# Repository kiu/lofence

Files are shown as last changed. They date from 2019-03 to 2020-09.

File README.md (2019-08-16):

# LoFence
LoFence is a [LoRaWAN](https://en.wikipedia.org/wiki/LoRa#LoRaWAN) capable IoT electric fence monitoring system running on the [The Things Network](https://www.thethingsnetwork.org/).

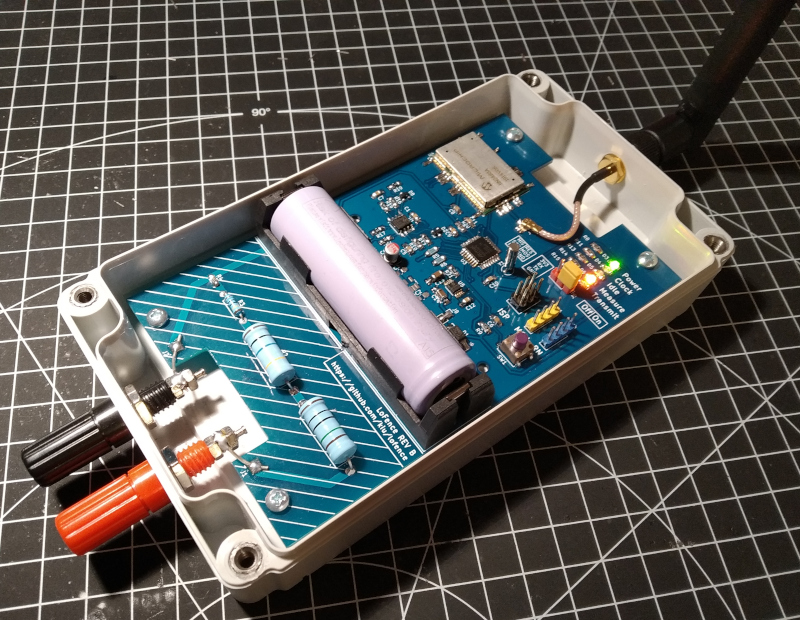
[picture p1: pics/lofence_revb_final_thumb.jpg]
lofence


# Backstory
A friend of mine is herding cattle and sheep on a small scale as a hobby. His setup is quite clever as his property has a creek running through, which enables him to let the animals live quite autonomously with minimal supervision. Unfortunately, he got called by the police a few times due to his sheep pulling a prison break. In theory a low maintenance system, but in reality things do happen. The car battery powering the electric fence energizer runs out of juice, a falling tree branch tears the fence down, or a tractor plows down a pole of the fence.

# Obvious solution
We need a monitoring system!

## Measuring
There are lots of ways to measure an electric fence. Try to hack the energizer’s built-in fault detection, measure current or do some fancy wave analysis of reflections on the line.

Too complicated for the initial build, let’s keep it simple by measuring voltage. Well, not a little voltage, but all the way up to 12 kV. Difficult, but a voltage divider with an op-amp will do fine. With this setup, we can measure any disconnects on the line between the energizer and the LoFence measuring point, even short circuits after the measuring point. Your mileage may vary though. This setup is heavily dependent on weather conditions, e.g. having dry soil will provide a different readout than after heavy rain.

## Connectivity
The more difficult challenge in a rural/agricultural area is connectivity. Cell coverage is quite spotty and of course it requires a monthly payment of some kind. Further, it’s such a 90’s solution to use a GSM module.

A few years ago LoRa appeared on the stage operating in the freely available [ISM bands](https://en.wikipedia.org/wiki/ISM_band) offering low speed, long range communication. Perfect for...sigh...IoT devices like the LoFence. While LoRa is great for point-to-point communication, LoRaWAN got established and offers a full suite of protocols enabling a standardized way to build communication networks based on LoRa. While there are commercial network operators like [Sigfox](https://www.sigfox.com) where you have to pay for their services, there is a global initiative called [The Things Network](https://www.thethingsnetwork.org/) to run an open LoRaWAN network that any device can join and use for free. Bingo.

Checking their [coverage map](https://www.thethingsnetwork.org/map) of course showed that the area of interest has no gateways in reach, but setting up a simple [gateway](https://raw.githubusercontent.com/kiu/lofence/master/pics/lofence_ttig.jpg) - in our case a [TTIG](https://www.thethingsnetwork.org/forum/t/ttig-the-things-indoor-gateway/22049) for ~80 Euro - easily solved the coverage problem. According to their [Fair Access Policy](https://www.thethingsnetwork.org/forum/t/limitations-data-rate-packet-size-30-seconds-uplink-and-10-messages-downlink-per-day-fair-access-policy/1300) our use-case of sending a few bytes of measurement data every few hours is perfectly fitted for their service. Let’s roll.

There are quite a few options to integrate LoRaWAN into your device. From the super cheap [RFM95W chipset](https://www.hoperf.com/modules/lora/RFM95.html) where your firmware has to do most of the action (e.g. used by the [Adafruit Feather](https://www.adafruit.com/product/3078)), up to the "expensive" turnkey solution like the [RN2483](https://www.microchip.com/wwwproducts/en/RN2483) which I chose. It does all the magic and will actively prevent you from breaking ISM band regulations regarding radio utilization. Nice.
 
## Build
The build is quite unspectacular. Spinning up a board with some AVR, put an antenna and the RN2483 on it, a big resistor divider with an op-amp and some resistors, debug LEDs and pin headers, an 18650 battery and a waterproof case. Et voila.

## Data Extraction
Having a node reporting its measurements to The Things Network is nice, but actually I want to do something with the data. Like sending an alert.

Extracting the data from TTN is easy, but I did it wrong anyways. First thing I stumbled upon was the [HTTP Integration](https://www.thethingsnetwork.org/docs/applications/http/). Everytime an uplink message is received from a node, the HTTP integration will trigger a POST message to a webserver of your choice. Great. So I wrote a Java service on my end to parse these messages and store them in a database for [grafana](https://grafana.com/) to [consume](https://raw.githubusercontent.com/kiu/lofence/master/pics/lofence_grafana_overview.png) later on. My implementation parses the uplink message, extracts the payload, stores the RSSI, SNR, number of gateways, etc. It can be found here: [ttn-http](https://github.com/kiu/ttn-http).

Later, I found out that there is a way nicer [MQTT Integration](https://www.thethingsnetwork.org/docs/applications/mqtt/), which also includes a ready to use Java implementation. A couple of hours could have been saved here.

The other thing I didn't figure out immediately is the [Payload Formats](https://raw.githubusercontent.com/kiu/lofence/master/pics/lofence_ttn_decoder.png) option in the TTN console. It lets you write simple javascript running inside The Things Network to decode your payload data and assign them to key-value pairs. When receiving a message through the HTTP Integration (or MQTT), that message will include the key-value pairs as json for easy consumption. Quite clever and easy to parse.

# Nitty-Gritty Details
Checkout the [pics](https://github.com/kiu/lofence/tree/master/pics) and [hardware](https://github.com/kiu/lofence/tree/master/rev_b) section including BOM, Schematic, PCB layout, firmware, etc.

# TTN
If you are inspired by this hack to build a LoRaWAN project on your own and join the The Things Network effort, register on their site and join their maker community on [slack](https://www.thethingsnetwork.org/community/toowoomba/post/join-us-on-slack).

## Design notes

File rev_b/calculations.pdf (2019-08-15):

Tabelle1

Seite 1

Ohm | 10000000 | 10000000 | 1000000 | 5800
Volt Drop | 5712,70791877 | 5712,707919 | 571,2707919 3,313370592884
Ohm Calc | 10050000 | 10070000 | 997000 | 5807,175
Ohm Real | 10050000 | 10070000 | 997000 | 5720
Volt Real | 5709,49195937 | 5720,854132 | 566,4043267 3,249581493293
| Standby | Measure | Transmit
mA | 0,012 | 20 | 50
Minutes | 59 | 0,5 | 0,5
mAh | 0,0118 | 0,166666667 | 0,416666667
Battery mAh | 3000
| Hours | Days | Weeks | Months | Years
Runtime | 5040,89 | 210,04 | 30,01 | 7,50 | 0,63

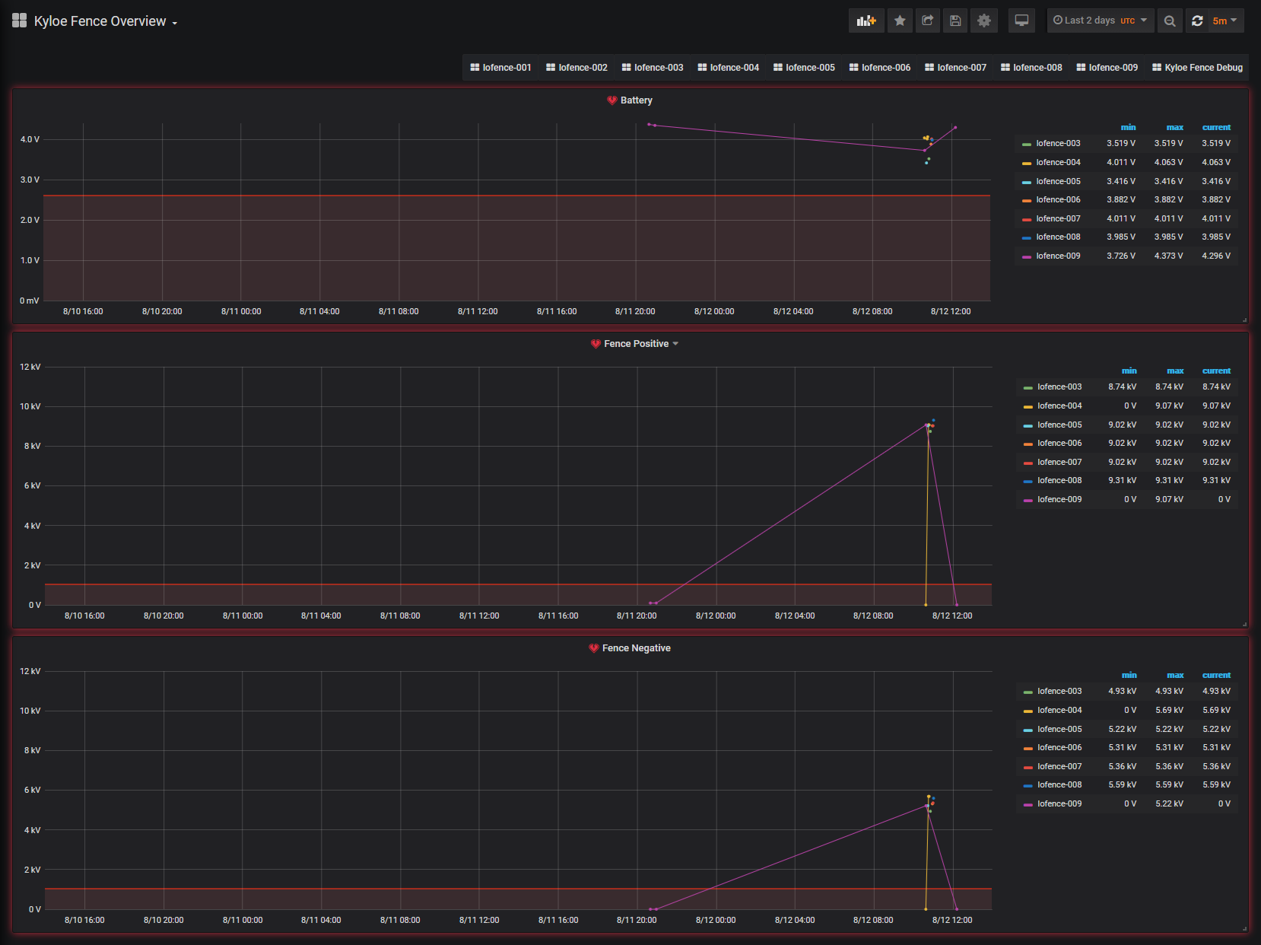
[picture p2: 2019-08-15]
pics/lofence_grafana_overview.png

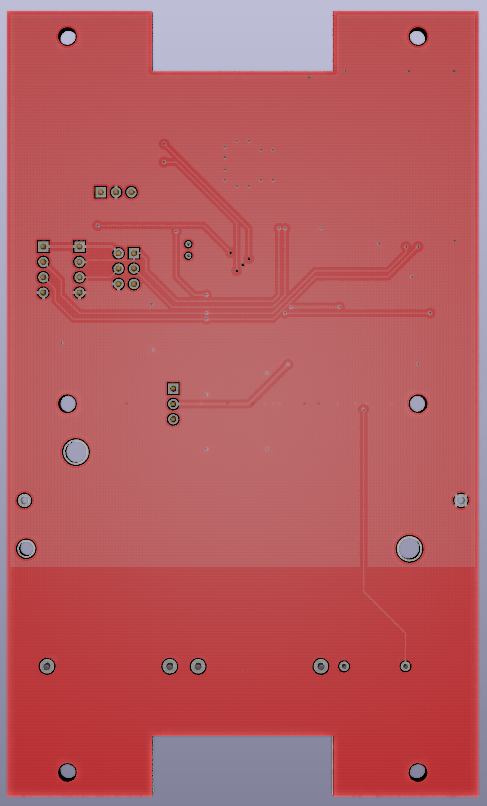
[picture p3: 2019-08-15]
rev_b/hardware/kicad_lofence_render_back.png

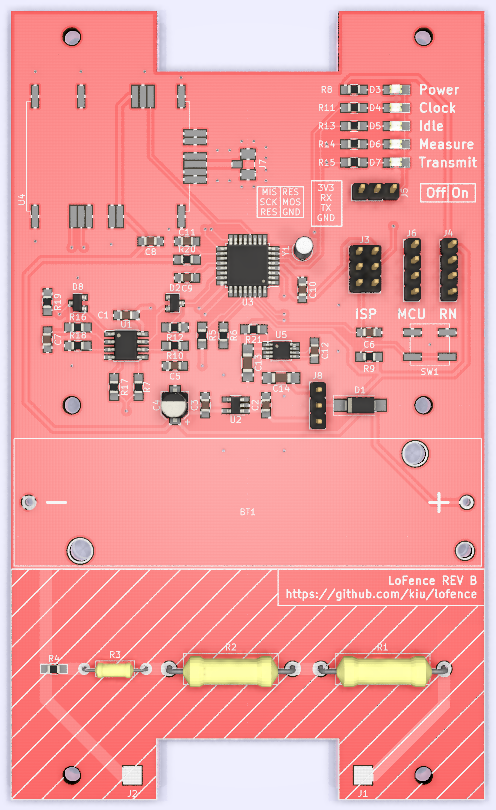
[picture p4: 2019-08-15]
rev_b/hardware/kicad_lofence_render_front.png

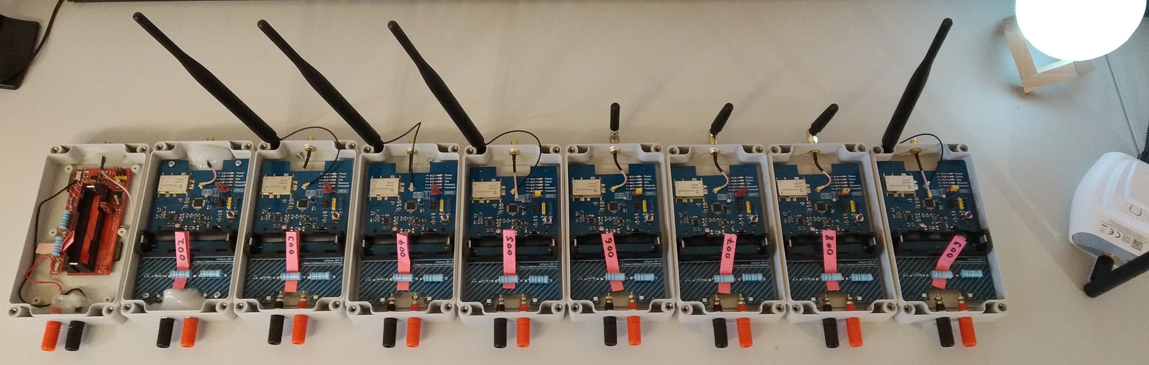
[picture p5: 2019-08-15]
pics/lofence_all_nine.jpg

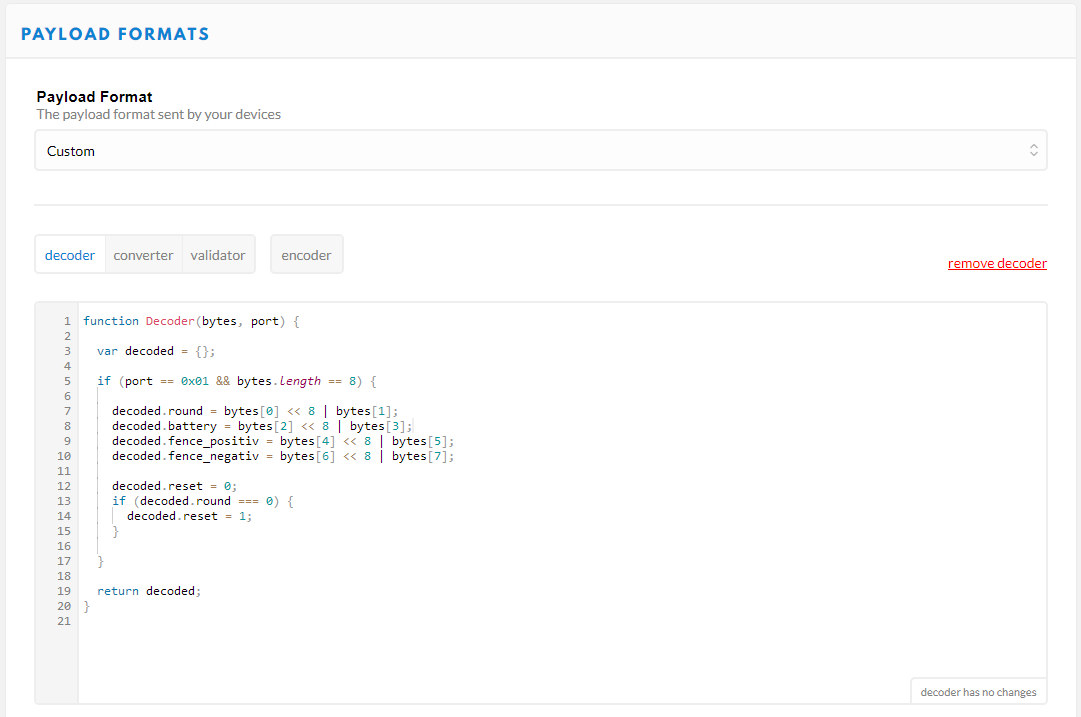
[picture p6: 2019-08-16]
pics/lofence_ttn_decoder.png

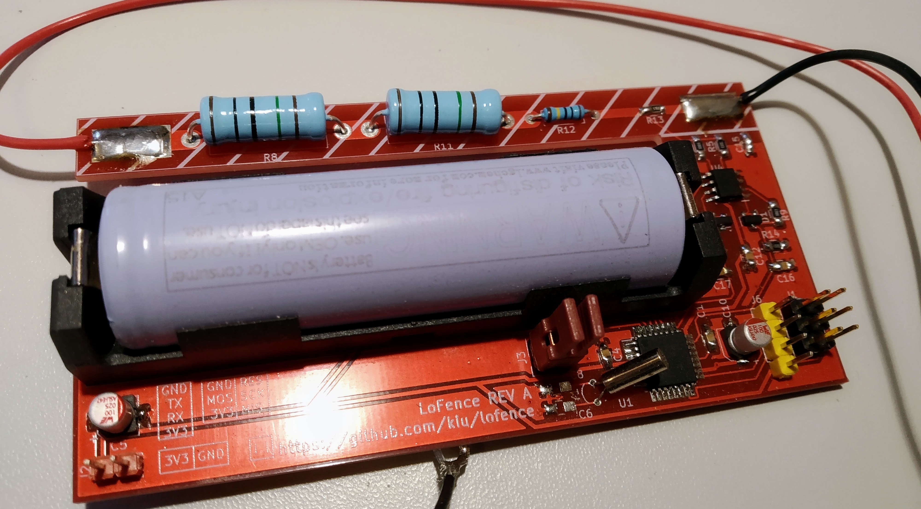
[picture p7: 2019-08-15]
pics/lofence_reva_proto.jpg

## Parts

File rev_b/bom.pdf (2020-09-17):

BOM
Symbol | Description | Req | +VAT | Price | Price (sum) | Provider | ID
| | | | MOQ 10
U1 | Opamp TLV9062 | 1 | 19 | 0,45 € | 0,54 € | http://www.mouser.de | 595-TLV9062IDR
(U2) | LDO MIC5504 | 0 | 19 | 0,10 € | 0,00 € | http://www.mouser.de | 998-MIC5504-3.3YM5TR
U3 | ATMega328PB-AU | 1 | 19 | 1,19 € | 1,42 € | http://www.mouser.de | 556-ATMEGA328PB-AU
U4 | RN2483 | 1 | 19 | 11,34 € | 13,49 € | http://www.mouser.de | 579-RN2483A-I/RM105
U5 | MCP1253-33X50 | 1 | 19 | 1,21 € | 1,44 € | http://www.mouser.de | 579-MCP1253T33X50IMS
J3 | 2x03 | 1 | 19 | 0,18 € | 0,21 € | http://www.mouser.de | 649-861400062YO2LF
J5 | 1x03 | 1 | 19 | 0,10 € | 0,11 € | http://www.mouser.de | 710-61300311121
J4, J6 | 1x04 | 2 | 19 | 0,14 € | 0,33 € | http://www.mouser.de | 710-61300411121
J7 | U.FL Straight Surface Mount Jack | 1 | 19 | 0,60 € | 0,72 € | http://www.mouser.de | 712-CONUFL001-SMD
C12, (C2, C3) | 1uF X7R 0805 | 1 | 19 | 0,04 € | 0,05 € | http://www.mouser.de | 963-EMK212B7105KG-T
C4 | 10uF 4x5.5 | 1 | 19 | 0,16 € | 0,19 € | http://www.mouser.de | 710-865080440002
C1, C5, C6, C7, C8, C9, C10, C11 | 100nF | 8 | 19 | 0,04 € | 0,37 € | http://www.mouser.de | 710-885012207098
C13, C14 | 10uF X7R 1206 | 2 | 19 | 0,12 € | 0,29 € | http://www.mouser.de | 963-LMK316B7106KL-T
R9 | 4k7 0805 | 1 | 19 | 0,04 € | 0,05 € | http://www.mouser.de | 667-ERJ-6ENF4701V
R5, R6 | 232R 0805 | 2 | 19 | 0,03 € | 0,08 € | http://www.mouser.de | 660-RK73H2ATTD2320F
R7, R10, R16, R17, R18, R21 | 100k 0805 | 6 | 19 | 0,03 € | 0,24 € | http://www.mouser.de | 71-RCG0805100KFKEA
R1, R2 | 10M 6kV 1W THT | 2 | 19 | 0,49 € | 1,16 € | http://www.mouser.de | 594-5073DM10M00J
R3 | 1M 700V | 1 | 19 | 0,28 € | 0,33 € | http://www.mouser.de | 594-5043DM1M000F
R4 | 5k76 0805 | 1 | 19 | 0,04 € | 0,04 € | http://www.mouser.de | 652-CR0805FX-5761ELF
R12, R19 | 1M 0805 | 2 | 19 | 0,07 € | 0,16 € | http://www.mouser.de | 71-RCA08051M00FKEA
R8, R11, R13, R14 | 60R 0805 | 4 | 19 | 0,04 € | 0,17 € | http://www.mouser.de | 652-CR0805FX-62R0ELF
R15 | 68R 0805 | 1 | 19 | 0,01 € | 0,02 € | http://www.mouser.de | 652-CR0805FX-68R0ELF
R20 | 47R 0805 | 1 | 19 | 0,01 € | 0,02 € | http://www.mouser.de | 652-CR0805FX-47R0ELF
D2, D8 | BAV70LT3G | 2 | 19 | 0,08 € | 0,19 € | http://www.mouser.de | 863-BAV70LT3G
D1 | Schottky Diode | 1 | 19 | 0,35 € | 0,42 € | http://www.mouser.de | 863-MBRA210LT3G
D3, D5 | LED Green 0805 2.10V | 2 | 19 | 0,15 € | 0,37 € | http://www.mouser.de | 604-APT2012CGCK
D4, D6 | LED Orange 0805 2.10V | 2 | 19 | 0,15 € | 0,35 € | http://www.mouser.de | 604-APT2012SECK
D7 | LED Red 0805 1.95V | 1 | 19 | 0,15 € | 0,18 € | http://www.mouser.de | 604-APHCM2012SURCK
Y1 | 32768hz | 1 | 19 | 0,18 € | 0,21 € | http://www.mouser.de | 449-LFXTAL002996BULK
BT1 | 18650 Battery Holder THT | 1 | 19 | 2,15 € | 2,56 € | http://www.mouser.de | 534-1043
SW1 | Pushbutton | 1 | 19 | 0,48 € | 0,57 € | http://www.mouser.de | 612-LL3301FF065QJ
- | Antenna 868Mhz | 1 | 19 | 2,56 € | 3,05 € | https://aliexpress.com | 32972870968
- | SMA/F.UL Pigtail | 1 | 0 | 1,29 € | 1,29 € | https://aliexpress.com | 32809523843
- | Binding Post Red | 1 | 19 | 0,31 € | 0,36 € | http://www.mouser.de | 474-PRT-09739
- | Binding Post Black | 1 | 19 | 0,31 € | 0,36 € | http://www.mouser.de | 474-PRT-09740
- | IP67 Enclosure 1555J2F17GY | 1 | 0 | 13,22 € | 13,22 € | http://www.conrad.de | 536525 – 62
- | Screw 2,9x6.5 | 6 | 0 | 0,07 € | 0,39 € | http://www.amazon.de | B01CLLUIJI
- | 18650 Battery 3350 mAh (Not recommended!) | 0 | 0 | 9,45 € | 0,00 € | B07NZVXJSP
- | PCB 130x78 | 1 | 0 | 1,60 € | 1,60 € | -

SUM
46,53 €
465,28 €

https://www.amazon.de

http://jlcpcb.com

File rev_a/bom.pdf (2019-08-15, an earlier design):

BOM

Page 1

Symbol | Description | Req | +VAT | Price | Price (sum) | Provider | ID
| | | | MOQ 10
U1 | ATMega328PB-AU | 1 | 19 | 1,19 € | 1,42 € | http://www.mouser.de | 556-ATMEGA328PB-AU
U2 | LDO MIC5504 | 1 | 19 | 0,10 € | 0,11 € | http://www.mouser.de | 998-MIC5504-3.3YM5TR
U3 | RN2483 | 1 | 19 | 11,34 € | 13,49 € | http://www.mouser.de | 579-RN2483A-I/RM104
U4 | Opamp TLV9062 | 1 | 19 | 0,45 € | 0,54 € | http://www.mouser.de | 595-TLV9062IDR
J1 | 2x03 | 1 | 19 | 0,18 € | 0,21 € | http://www.mouser.de | 649-861400062YO2LF
J2 | 1x02 | 1 | 19 | 0,07 € | 0,08 € | http://www.mouser.de | 649-861400021YO2LF
J3 | 2x02 | 1 | 19 | 0,12 € | 0,15 € | http://www.mouser.de | 649-86140042YO2319LF
J6 | 1x04 | 1 | 19 | 0,14 € | 0,16 € | http://www.mouser.de | 710-61300411121
C2, C3 | 1uF X7R 0805 | 2 | 19 | 0,11 € | 0,27 € | http://www.mouser.de | 81-GRM21BR71C105JA1K
C5, C10 | 10uF 4x5.5 | 2 | 19 | 0,16 € | 0,37 € | http://www.mouser.de | 710-865080440002
C1, C4, C9, C11, C12, C13, C16, C17 | 100nF | 8 | 19 | 0,04 € | 0,37 € | http://www.mouser.de | 710-885012207098
R2 | 4k7 0805 | 1 | 19 | 0,04 € | 0,05 € | http://www.mouser.de | 667-ERJ-6ENF4701V
R3, R4 | 232R 0805 | 2 | 19 | 0,03 € | 0,06 € | http://www.mouser.de | 660-RK73H2BTTD2320F
R5, R6, R7, R9, R10 | 100k 0805 | 5 | 19 | 0,03 € | 0,20 € | http://www.mouser.de | 71-RCG0805100KFKEA
R8, R11 | 10M 6kV 1W THT | 2 | 19 | 0,49 € | 1,16 € | http://www.mouser.de | 594-5073DM10M00J
R12 | 1M 700V | 1 | 19 | 0,28 € | 0,33 € | http://www.mouser.de | 594-5043DM1M000F
R13 | 5k76 0805 | 1 | 19 | 0,04 € | 0,04 € | http://www.mouser.de | 652-CR0805FX-5761ELF
R14, R15 | 1M 0805 | 2 | 19 | 0,07 € | 0,16 € | http://www.mouser.de | 71-RCA08051M00FKEA
D1, D2 | BAV70LT3G | 2 | 19 | 0,08 € | 0,19 € | 863-BAV70LT3G
L1 | 10uH 0805 | 1 | 19 | 0,06 € | 0,07 € | http://www.mouser.de | 963-LBR2012T100K
L2 | Ferrite 0805 220R 2A | 1 | 19 | 0,06 € | 0,07 € | http://www.mouser.de | 81-BLM21P221SG
Y1 | 32768hz | 1 | 19 | 0,18 € | 0,21 € | http://www.mouser.de | 449-LFXTAL002996BULK
BT1 | 18650 Battery Holder THT | 1 | 19 | 2,15 € | 2,56 € | http://www.mouser.de | 534-1043
- | Antenna 868Mhz | 1 | 19 | 6,03 € | 7,18 € | http://www.mouser.de | 815-CAQ190012-S868
- | Binding Post Red | 1 | 19 | 0,31 € | 0,36 € | http://www.mouser.de | 474-PRT-09739
- | Binding Post Black | 1 | 19 | 0,31 € | 0,36 € | http://www.mouser.de | 474-PRT-09740
- | IP67 Enclosure 1555J2F17GY | 1 | 0 | 13,22 € | 13,22 € | http://www.conrad.de | 536525 – 62
- | 18650 Battery 3350 mAh (No Protection Circuit, Amazon Link not recommended) | 1 | 0 | 9,45 € | 9,45 € | B07NZVXJSP
- | PCB 100x50 Red | 1 | 0 | 1,41 € | 1,41 € | -

SUM
54,26 €
542,64 €

http://www.mouser.de

https://www.amazon.de

http://www.seeedstudio.com

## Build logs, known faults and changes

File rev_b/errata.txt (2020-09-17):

1) Power supply
I never used a DC to DC converter before and wasn't sure if it could interfere with the RN2483 or ADC.
Therefore in addition I placed a LDO as a backup on the board as well.
The DC to DC converter works fine, so the LDO (U2, C2, C3) can be left unpopulated.

2) Resistor divider
Instead of
  [Fence+]--[10M]--[10M]--[1M]--[Measure]--[5k8]--[Fence-/GND]

I probably should have done
  [+12kV]--[10M]--[1M]--[Measure]--[5k8]--[GND]--[10M]--[Fence-]

3) The BOM of REV B was published with a wrong resistor value for R4. The correct value is 5k76.

4) Fixed silkscreen for ISP connector (3V3 in upper right corner instead of RES), but did not regenerate gerbers and other exports.

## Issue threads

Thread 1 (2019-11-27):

How to re-program RN2483 with your board layout?

kevinkngo, 2019-11-27:
Hi kiu,

I really appreciate you sharing this project. This is my first IoT project where I've started to enter the world of AVRs and PCBs (which is very exciting!).

I have actually gotten your PCB design fabricated, then I soldered on the components you listed in your BoM and loaded the firmware you provided onto the MCU... And it works great.
[Note: I actually have the RN2903 instead of the RN2483 - but they both work and are programmed very similarly].
I am currently trying to re-program the RN2903 soldered onto my PCB using the LoRaDevUtility ([Microchip documentation](http://ww1.microchip.com/downloads/en/devicedoc/40001847a.pdf)) and the RN UART pins you have provided.

However, I believe that due to the way you have set out your board, it is very difficult to do this. I could initially see the RN2903 in the LoRaDevUtility (see screenshot #1), but had to continuously hold down SW1 to keep the UART connection "alive".
I then tried to update the firmware on the RN2903 but I accidentaly "bricked" the chip currently on my board because the UART connection disconnected while the firmware was updating. Now whenever I try to upload firmware onto the RN2903 now, it keeps disconnecting and does not allow me to upload any firmware (see screenshot #2).

I am more than happy to grab another RN2903 and try again, but I'm hoping that you could provide some advice before I continue.

Do you have any recommendations about how I can re-program the RN2903/RN2483 using your board layout? Have you tried uploading different firmware onto the RN2483 yourself?
Since you manufactured so many boards, I am curious whether if you've thought about how you would update the firmware on the RN2483 on these boards (without taking it off?).

Thanks,
Kevin

Screenshot #1 - initially, can see RN2903 in LoRaDevUtility:
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

Screenshot #2 - cannot stay connected to RN2903 and upload firmware. Continuously disconnecting like below (I am using COM4 as my UART serial port):
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

kiu, 2019-11-27:
Hi Kevin,

I have to admit, I didn't think much about how to upgrade the firmware of the RN module. Or at least not in an user friendly way.
I would probably flash the AVR with a new config disabling the RX/TX pins, so they won't interfere with the RN module. Then upload the the RN firmware as you did.

If the RN module leaves bootloader mode, you could try to send the "eraseFW" command.

Hit me up on https://www.thethingsnetwork.org/community/toowoomba/post/join-us-on-slack (user: kiu).

kiu, 2019-11-29:
For the record.

Flashing a NOP version of lofence with RX/TX pins disabled (Atmel Start Config) and issuing a single RESET does the trick.

`int main(void) {
	atmel_start_init();
	_delay_ms(100);
	RN_RESET_set_level(false);
	_delay_ms(100);
	RN_RESET_set_level(true);
	_delay_ms(100);
	while (1) {
	}
}
`

jpmeijers, 2021-11-03:
I was struggling a little to do the firmware upgrade. Mostly because I am not familiar with Atmel Start. So let me document what I did in case someone else stumbles upon this thread.

1. Comment out the content of the `int main(void)` function and replace it with the contents of the main function as posted above.
2. Open src/driver_init.c and comment out the lines `USART_0_initialization();` and `USART_1_initialization();`.
3. Upload to LoFence board.

Because I could not find the Microchip firmware upgrade tool from an official source, and the one I did find didn't want to work, I looked for a different way to flash the firmware. I ended up using https://github.com/SodaqMoja/RN2483FirmwareUpdater

Luckily I had a Sodaq Explorer at hand to do the update, but I had to change the firmware to program the external RN2483 and not the onboard one on the Explorer. In RN2483FirmwareUpdater.ino on line 17 I replaced `Serial2` with `Serial`. `Serial` is the UART on pin 0 and pin 1.

Connection between the Explorer and LoFence is as follows:

| Explorer | LoFence J4 |
| -- | -- |
| 3.3V | pin 1 (3.3v) |
| D1 (TX) | pin 2 (RX) |
| D0 (RX) | pin 3 (TX) |
| GND | pin 4 (GND) |

Closed 2019-11-29.

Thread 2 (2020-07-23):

missing symbols

toozie21, 2020-07-23:
Nice design!

I am new to KiCad and when I opened your project there were missing symbols for the schematic (like for the RN2483).  Are those symbols something that you drew by hand? I haven't looked at the PCB yet, but I will let you know if I see similar issues there.

kiu, 2020-07-23:
Uh, thanks for pointing that out. I accidentally gitignored the cache.lib file.
Please update and check again.

toozie21, 2020-07-23:
> Uh, thanks for pointing that out. I accidentally gitignored the cache.lib file.
> Please update and check again.

Thank you, that did solve that issue.  Though it seemed to cause a different one after I updated...
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

kiu, 2020-07-23:
Odd. I did a clean install of kicad on a machine where I never used kicad on before. Did a git clone and get no errors. I do get a wizard though, but that works fine.

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

toozie21, 2020-07-23:
Weird. What version of KiCad?

kiu, 2020-07-24:
I installed latest stable 64bit Windows Version, that is 5.1.6
https://kicad-pcb.org/download/windows/

toozie21, 2020-07-24:
> I installed latest stable 64bit Windows Version, that is 5.1.6
> https://kicad-pcb.org/download/windows/

I was using Ubuntu and it was one minor version behind.  I installed it on my Windows laptop to make it easier and it seemed to load up fine, so I think you solved the problem, thanks!!

Closed 2020-07-24.

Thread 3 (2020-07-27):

Question on battery

toozie21, 2020-07-27:
Not an issue, just a question.

In the BOM you say this for the battery
`18650 Battery 3350 mAh (Not recommended!)`
But I don't see any explanation anywhere for why you don't recommend it. Did you have issues? TIA

Alex9779, 2020-08-20:
Yeah I am interested in an answer on this too...

kiu, 2020-08-20:
If I remember correctly, the battery doesn't have a security circuit. Therefore I wouldn't want to recommend it. Otherwise nothing wrong with it. Works fine for me.

toozie21, 2020-08-20:
> If I remember correctly, the battery doesn't have a security circuit. Therefore I wouldn't want to recommend it. Otherwise nothing wrong with it. Works fine for me.

That is correct. I thought that if you take an additional step, it would need the protection and probably charging circuitry. I think it is perfect as is though.

I just wanted to make sure that you didn't have one blow up on you, and we're suggesting a different brand 😁.
 Thanks again for the awesome design.

Closed 2020-08-20.

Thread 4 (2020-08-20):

Question on voltage divider errata

Alex9779, 2020-08-20:
Just another question on the errate you did on the voltage divider.
Could you just explain what you meant with that?
I am thinking of rebuilding your design but also I am puzzled what the difference is as I am not really sure what you mean with "Fence+", "Fence-" and "12kV".
My fences have just one pole, when I measure them using a normal tester the tester is connected to the ground by a nail and one end goes to the fence. There is no + and - but just a +, - is ground...
What am I missing?
Thanks for your efforts in advance...

kiu, 2020-08-20:
The left side is REV B and right side is the potential improvement. The hot wire of your fence is connected at the top, bottom has the earth connection (rod/spike in the ground)

I am wondering in the errata, if its clever to switch to the design on the right, where the pcb ground and earth of the fence are decoupled by 10M.

Does that help?

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

Alex9779, 2020-08-21:
Yeah cool thanks, I think I will calculate that for me to see the numbers too but the changed labels helped a lot...

frederickjh, 2023-04-10:
> Yeah cool thanks, I think I will calculate that for me to see the numbers too but the changed labels helped a lot...

@Alex9779 Thanks for posting this issue. I was wondering the same thing. Thanks to @kiu for the diagram explaining it.

Did either of you ever build and test this improved voltage divider?

Just wondering and trying to not reinvent the wheel.

I see one commercial product (Fence Hawk) on the market that builds the voltage divider in a piece of PVC pipe with PVC caps on the ends and stainless steel bolts in the caps to connect to the fence and ground. They then run a low voltage wire run to the detector circuit. This seems like an interesting design.

Alex9779, 2023-04-10:
I built them according to the errata and they have been working fine since then, that is the changed voltage divider and also removing the obsolete LDO circuit.

Closed 2020-08-21.

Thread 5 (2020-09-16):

R5, R6 BOM order number wrong

Alex9779, 2020-09-16:
R5 and R6 in the BOM have a 0805 footprint but the Mouser part number resolves to resistors with a 1206 case.
Think it is just a typo because there exists pretty much the same resistors in 0805 with order number 660-RK73H2**A**TTD2320F instead of 660-RK73H2**B**TTD2320F.

kiu, 2020-09-17:
Good catch!
https://github.com/kiu/lofence/commit/79e2fb9587586af6832cf9452c6af343f834de3f

Closed 2020-09-17.

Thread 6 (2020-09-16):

Silk screen of ISP has 'RES' twice

Alex9779, 2020-09-16:
No idea if this is intended but doesn't have to be 'RES' in the upper right corner '3V3' of the silk screen for the ISP connector?

kiu, 2020-09-17:
Uh, yes.
https://github.com/kiu/lofence/commit/0af46fa1ba887103b02b0fecc750f6ab15897427

Closed 2020-09-17.

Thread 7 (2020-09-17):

Issues regarding the RN2483 LoRa module and LoRa logic

Alex9779, 2020-09-17:
Taking the next step to get the project to use I had to set up a LoRa gateway (did this already earlier and played with some other modules), learned about TTN and ChirpStack.
And I stumbled over a few things I would like to mention, no idea if you are aware of them or not.

The overall usage of LoRa does not seem to fit any guidelines, at first you use ABP for joing, that's ok but not recommended so I changed the firmware to use OTAA which then has some other things to follow like saving the join information accross power cycles. I am still working on that, I think of totally rewriting the firmware, if ready I will put it up in my fork.

Another thing is that the module uses not the EU868 specs if you do a "sys factoryRESET", you have to do a "mac reset 868" also to load the EU868 channel defaults deactivating the use of channel 3-15 (actually 7, because 8-15 are disabled by default). This has no effect if using TTN because a TTN gateway listens on all 8 channels but recommended is to use only the first 3 (0-2). I had that problem when using a gateway created with ChirpStack which just listens on channel 0-2 by default.

Last the data rate. It is left at default DR0 which is SF12BW125 it seems with no ADR while ADR is mandatory for SF11 and SF12 and based on https://avbentem.github.io/airtime-calculator/ttn/eu868/8 at DR0 only 20 messages per day are allowed and accepted by TTN but the firmware does a measurement once every hour. So if your devices use that firmware in public I would at least recommend to change it to use DR2.

Just a side note: thanks for the great project, I don't think I would have been able to get a working PCB without many prototypes and in a short time as I have, saved my a lot of trouble, time and money...

kiu, 2020-09-17:
Thanks for sharing your insights!

> The overall usage of LoRa does not seem to fit any guidelines, at first you use ABP for joing, that's ok but not recommended so I changed the firmware to use OTAA which then has some other things to follow like saving the join information accross power cycles.

As the area I am trying to cover has really low coverage, I chose to use ABP to increase the chance of packets reaching the gateway. Didn't want to rely on additional OTAA traffic. But you are right, it is recommended and way more convenient.

> I am still working on that, I think of totally rewriting the firmware, if ready I will put it up in my fork.

Sweet.

> Another thing is that the module uses not the EU868 specs if you do a "sys factoryRESET", you have to do a "mac reset 868" also to load the EU868 channel defaults deactivating the use of channel 3-15 (actually 7, because 8-15 are disabled by default).

Hmmm, odd. I checked the Command Reference and everything points me towards that the 868 parameters are the defaults of the module. It explicitly says "The default settings consider only the three default channels (0-2), and their default duty cycle is 0.33%.", but I never verified it. Do you have more information on this?

> Last the data rate. It is left at default DR0 which is SF12BW125 it seems with no ADR while ADR is mandatory for SF11 and SF12

True, I didn't know that. https://github.com/kiu/lofence/commit/61f52703dbc37d511e447d4d42a77dffc8d7a1df

> and based on https://avbentem.github.io/airtime-calculator/ttn/eu868/8 at DR0 only 20 messages per day are allowed and accepted by TTN but the firmware does a measurement once every hour. So if your devices use that firmware in public I would at least recommend to change it to use DR2.

Also true, changed it as well.

Alex9779, 2020-09-17:
Yeah well, the module surprised me also.
The overall appearence made me also think this is plug and play but there are some drawbacks.
Trying to get OTAA working the way its meant to be, that is just one join when the device is provisioned and hopefully never again, which is considered best practice, lead into other issues.
I found an Arduino lib for the module, but this is not doing this also very well, I think of taking that and rewriting and using it for this project, most of the code should be copy paste but class init and comm must be changed for the Atmel.

Alex9779, 2020-09-17:
This is the lib I want to adapt: https://github.com/jpmeijers/RN2483-Arduino-Library

Alex9779, 2020-09-17:
BTW I checked all I wrote by directly commanding the module with a terminal app running firmware 1.0.5, that version you get if you order using the number in your BOM, no idea if the other available version does the same, reflashing seems not so easy, I found a script on Github too but I don't want to try just to prove something...

Alex9779, 2020-10-08:
Well it seems I didn't have the time (yet) to do what I wanted, I just modified the firmware to use OTA and reorganized a little.
I wrote a simple python script for initializing a fresh RN2483 module for OTA.
My 6 devices are up and running, 2 in the wild, 4 on my desk waiting for cables to connect them to the fence.
Monitoring works just fine.
Unfortunately I modified the PCBs with a KiCAD nightly build and I am not sure if I should publish that yet. I will when v6 is released and then also along with my changed firmware, so maybe January...

Closed 2020-10-08.

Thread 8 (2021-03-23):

op-amp power supply

4Inno, 2021-03-23:
Hey there,
great project! Isn't the op-amp missing the supply power? ADC_POWER is only conntected to the uC. Or am I missing something?
Best regards

kiu, 2021-03-23:
The ADC_POWER is directly powering the opamp from the uC everytime a measuring cycle is run. That way the op-amp does not consume any power when its not needed as the uC can turn it off.

4Inno, 2021-03-24:
Thank you! I will close the issue.

Closed 2021-03-24.

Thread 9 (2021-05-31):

RN2483 send timeout?

thomasdupas, 2021-05-31:
What firmware of the RN2483 are you running, 1.0.5 or an earlier version? And what settings did you use on TTN side for the device?

I'm having some issues where the RN2483 sometimes doesn't give a response anymore to a TX command.
It would do multiple rounds OK, and then suddenly it acknowledges the command to send an unconfirmed message, but after ~1 hour it still sits there with no response on the UART from the RN seemingly (I didn't tap the UART yet directly from the RN in parallel, will try that). In the docs of the RN2483 there is a possible timeout response mentioned, so should it need to be set explicitly perhaps?

example:
```
Sleeping for 4320 seconds

Round: 3
Measuring
Measuring battery: 4684 mV
Measuring fence positive: 0 V
Measuring fence negative: 0 V

Transmitting
RN2483 wakeup and baud change
RN2483 RX clearing
RN2483 TX: mac join abp
RN2483 RX: ok
RN2483 RX: accepted
RN2483 TX: mac get upctr
RN2483 RX: 25
RN2483 TX: mac set pwridx 1
RN2483 RX: ok
RN2483 TX: mac tx uncnf 1 0003124C00000000
RN2483 RX: ok
RN2483 RX: mac_tx_ok
RN2483 TX: mac save
RN2483 RX: ok
RN2483 TX: sys sleep 86400000

Sleeping for 4320 seconds

Round: 4
Measuring
Measuring battery: 4658 mV
Measuring fence positive: 0 V
Measuring fence negative: 0 V

Transmitting
RN2483 wakeup and baud change
RN2483 RX clearing
RN2483 TX: mac join abp
RN2483 RX: ok
RN2483 RX: accepted
RN2483 TX: mac get upctr
RN2483 RX: 26
RN2483 TX: mac set pwridx 1
RN2483 RX: ok
RN2483 TX: mac tx uncnf 1 0004123200000000
RN2483 RX: ok
```

/edit: found some other references to this
https://www.thethingsnetwork.org/forum/t/rn2483-timing/36278
https://www.microchip.com/forums/m1101599.aspx

So for now I've put a (naive) 5 second timeout in the rn2483_rx() function to cope with this. Will let it run again overnight and see how it behaves

kiu, 2021-05-31:
Hmmm. Unfortunately I haven't seen this problem before. I have 10 devices running and I didn't observe a device being stuck. Or - to be more precise - I didn't see it while testing. The devices are in the field and maintained by friend. I wouldn't notice if he reboots devices sometimes.

I am pretty sure that all my devices run RN2483 firmware 1.0.5.

Adding the timeout is a good idea anyways. Please provide feedback on your experience.

kiu, 2021-05-31:
Actually I can see resets as I am monitoring them. But I don't know if they were intended (device was moved / battery changed) or because of a lock up.

Each spike is reset on a device.

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

thomasdupas, 2021-06-01:
For now it's going steady again, perhaps too soon to tell. But I guess the timeout doesn't hurt anyhow.

I saw a prior ticket with some potential changes ( https://github.com/kiu/lofence/issues/7 ) which didn't go through yet since kicad 6 isn't released yet. I'll probably hop on that wagon as well, since updating the keys and creating a custom hex file gets error-prone very quickly.

I'll probably create some pyserial wrapper around a json/config file which has the hweui's and TTN keys. Then it can do the RN<->TTN config mapping by itself and every AVR can have the same firmware (PS, why the EEPROM save every time, it's only altering those settings once, not concerned about EEPROM wear?).

Didn't use lorawan before, so have to read up on OTAA vs ABP and see what that entails possibly

kiu, 2021-06-01:
> (PS, why the EEPROM save every time, it's only altering those settings once, not concerned about EEPROM wear?).

I believe - its been a while - that the frame counter is only persisted on a "mac save". As I have enabled that for the devices in the TTN console, I need to ensure that the value is not lost. Otherwise the RN2483 on a reboot will start with frame counter 0 and the messages are discarded. There is probably no need to enable frame counters (replay attacks aren't a strong vector in my scenario).

> Didn't use lorawan before, so have to read up on OTAA vs ABP and see what that entails possibly

I didn't use OTAA for my devices, as there is really bad coverage in the area I am setting them up. OTAA - not on every message though - requires additional packets being transmitted to join the network and there would be a higher chance of packet loss.

Alex9779, 2021-06-01:
I followed this issue and because you mentioned #6 here my comment.
I wanted to change and use a ready to go lib for the RN module, but as it goes it didn't have the time and just changed the code to do what I need and thought was right.
That is burning the keys to the RN module using an extra script before programming the ATmega and then using soft ABP joining.
I recently switched to an OTAA rejoin when the device gets reset/restarted because of some issues witch my LoRa gateway sometimes having troubles with fCnt of packets and re-joining resets that counter and starts over... This is how my other LoRa sensors are doing it and as the devices have a very long uptime I don't see an issue there anymore. Initially I thought re-joining should not occur on every restart but what I really meant was not too often and if a device is up for a year and then the battery has to be changed this is not too often for a re-join...
One or two times since I use the devices I had a hanging RN module, the device didn't post updates, I opened it and the transmit LED lit continually but I wasn't able to debug and get the cause if it. A restart solved it...
I thought of implementing a watch dog but I have no idea if that is even possible with the ATmega chip...

thomasdupas, 2021-06-01:
@Alex9779 "One or two times since I use the devices I had a hanging RN module, the device didn't post updates, I opened it and the transmit LED lit continually but I wasn't able to debug and get the cause if it. A restart solved it..."
That's exactly what I had yesterday / see start of issue ticket.

What I changed (apologies for the ugly code, this is outside my comfort zone ;-)) to have a ~5 second timeout
```
void rn2483_rx() {
	char nc = 0x00;
	uint8_t len = 0;

    // erase buffer_rn to make sure it doesn't contain data from prior read
    memset(buffer_rn, 0, 255);

    // do 5000 loops, bit naive way to yield a 5 second timeout
    for(int i = 0; i < 5000; i++){
        if (USART_0_is_rx_ready()) {
            nc = USART_0_read();
            buffer_rn[len] = nc;
            len++;
            if (nc == '\n') {
                break;
            }
        } else {
            _delay_ms(1);
        }
	}
	buffer_rn[len+1] = '\0';

	#ifdef DEBUG
	debug("RN2483 RX: ");
	debug(buffer_rn);
	#endif
}
```

Alex9779, 2021-06-01:
Well it is hard to test, maybe have a look in that lib and see if they have implemented some kind of watch dog:
https://github.com/jpmeijers/RN2483-Arduino-Library

thomasdupas, 2021-06-01:
no watchdog at first glance, but timeouts on the serial reads on many places
like
```
        _serial.setTimeout(30000);
        receivedData = _serial.readStringUntil('\n');
        _serial.setTimeout(2000);
```

Alex9779, 2021-06-01:
Yeah well, as already said I have it running in a way it suits me...
If I wanted to sell those devices then yes, the firmware would need a rework, but for now I don't need it.
A hang rarely happens, most devices didn't have a single hang until the battery ran out so...

kiu, 2021-06-01:
It is my understanding that once the module hangs, it won't recover later on. Can you confirm that? If that is the case, you would need to reset the module in case your timeout is triggered: rn2483_init();

It is also possible to integrate the hardware watchdog into the system, but be aware that the current code immediately starts to send a packet through TTN. A device with problems restarting through the watchdog all the time, could violate the fair use policy of TTN. The RN2483 itself covers any regulatory violations, but who knows what the module actually will do, if it hangs/crashes. Probably best solution for a watchdog solution would be to go to sleep after startup to insure proper delays in case the device goes roque.

Alex9779, 2021-06-01:
As far as I can tell from other LoRa devices TTN fair use is one thing, local regulations something other and what a device does also.
I don't use TTN because for my fence monitoring the fair use is not enough for me to get alerts in time. I have my own gateway on Chirpstack.
TTN just ignores packets above the fait use, you won't get them in your app.
What happens if your device constantly breaks local restrictions I can't tell... I think it depends if you really interfere with something important then they come and analyse.
My approved devices for example try to join every 30 seconds after a reboot I think but I have no idea for how long if they don't get an answer.
That is much above what TTN allows.
I agree if the module hangs and you have to reset you also reset the regulation restrictions and that way you can break them, send more packets than allowed.
And as far as I know the approved devices have some kind of timeout, they try but stop after some time and require a manual reset to try again to not overwhelm the band...

thomasdupas, 2021-06-01:
Just documenting it here, for future reference.
I tried the absence of the eeprom save command, but that's indeed needed to keep track of the frame counter. It confused me that the docs said it was needed after `mac set <xyz>` commands (and there exists an explicit downlink/uplink frame counter set command), but implicitly the module is bumping that every transmission I guess, hence the need for the save.
Tested here below, The last 2 cycles was with firmware without the mac save command (and a reset in-between)

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

As for the RN reset / hang, very possible indeed, but hard to provoke to be certain. For testing purposes I'll leave it out for now and see what happens.

Alex9779, 2021-06-01:
I used that mac save in my firmware but only every 100 uplinks to save the eeprom from wearing out, on a new start I increased the counter by 100 to be after any count between where the gateway might be...
But I changed to a rejoin on a reset so no need to save for now...

Alex9779, 2021-08-25:
I want to share some recent impressions on this topic.
I do not use TTN but have an own gateway running ChirpstackOS. I stumbled over some special handling in the Chirpstack code regarding the RN2483 and the LoRa power index sent to the device if in ADR mode.
The issue seems to be that the RN2483 does not handle a power index of 0 properly.
Though this seems to be taken care of in the base code of Chirpstack I created an own ADR algorithm plugin and changed it so power index 0 is never used despite some other changes I want to have for my installation.
Since I use (about 1 month at the time of writing) this ADR algorithm for my LoFence devices I never had a hanging device again.

Alex9779, 2021-08-25:
here is the code in Chirpstack I referred: https://github.com/brocaar/chirpstack-network-server/blob/3971570b77c79c1cfd184b6f06a4f1770b5a0db0/internal/maccommand/link_adr.go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

Alex9779, 2021-08-25:
Oh and yes I know there is firmware 1.0.3 mentioned, i checked one device and I have 1.0.5 on it.
But since there was a problem in 1.0.3 no idea if the fix works properly.
I will monitor and see how long the system is stable with the new ADR for the RN2483 and report if I see a hanging device again...

Alex9779, 2021-09-20:
About a month passed and system still stable, no hanging devices after changing to my ADR algorithm.
I had one device having an issue but it turned out the crystal had a connection issue and the clock didn't get a signal so the device didn't wake up after initial join and first measurement.
I changed batteries of all six devices yesterday, all joined without issues and sent ~200 updates...

Closed 2023-04-12.

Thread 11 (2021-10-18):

"round" counter really necessary

jpmeijers, 2021-10-18:
LoRaWAN has a frame counter that also increments every transmission. Does the "round" counter really add any extra usefulinformation?

Currently this project uses ABP and the frame counter will not reset during a power cycle. One will therefore not see a restart in the frame counter, and this "round" counter might be useful.

I'm however of the opinion one should switch to OTAA. I'll file a PR for OTAA in the coming days.

Closed 2023-04-12.

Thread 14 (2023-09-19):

Impulse measurement

Inrebusillis, 2023-09-19:
I have built the divider and the amp circuit and send the signal to a Dragino LSN50 V2 and V3 to make easy the LoRa part for me as I have this module from othes project,
everything working excellent BUT:
- the fence ( big bully up to 12kV is powered by voltage impulse ( about 30 ms)  every 0.8 seconds so Is not constantly all the time powered ( my unsterstand)
- the LNS50 wake up take a measurement from the circuit and go sleep for the next 20 minutes

obviusly the probability that the impulse is done just when the module is awake is really low.

How can measure the voltage and "hold the value" ( measure the impulse) till the sending module is awake again?
Or I missing something ?
thanks

jpmeijers, 2023-09-19:
Your understanding is correct.

Each time the Atmega 328p wakes up (every hour), the firmware samples the ADC for 15 seconds, at a rate of 250kHz, storing the max and min values it encounters. It will therefore measure more than 15 pulses in a row, storing the maximum sample, of the maximum pulse, and report that as the voltage.

You can have a look at how the ADC is set up here:
https://github.com/kiu/lofence/blob/9a1d09bd57b84be4a4ec193df7fd8c69c1f981a8/rev_b/firmware/LoFence/main.c#L52

Inrebusillis, 2023-09-19:
so to built it I have to use the full project.
let me ask you: I have a friends/farmer that need to 7 of these,
I am already running a TTI network.
Can I use your project? which conditions?
I would like to have a short chat with you, could you send me your tel via PN?
Thanks

Alex9779, 2023-09-19:
I tried the same about a year ago, I developed several iterations of a "sensor module" using just the divider and the opamp, one verison also used a smaller AVR MCU but I wasn't able to work reliable.
One problem is the spefic characteristics of the ADC of the ATmega 328PB of the original design.
The other is the firmware of the LSN50 which is not capapable of "waiting" a defined time frame for a function running in the background to get the max value of several impulses.
I tried to program a new firmware using the ADC of the LSN50 itself but didn't succeed.

ATM I am finalizing a V2 version with a smaller case, a different LoRa module and two 18650 or 18500 batteries, that is not fixed yet...

Alex9779, 2023-09-19:
This is how one version looked like:
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

And this how my current design looks like:
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

Alex9779, 2023-09-19:
One thing to consider is that the circuit with the OpAmp to "store" the peak and let the LSN ADC measure that is that it also uses current and from what I calculated the LSN battery would last about 2 years when measuring every 5 minutes like I do now.
And that battery is not chargeable.
This was something I wanted to accept and which also would lead to some money each year or two to keep it running...
In the end I chose to redesign the original device to have more lifetime, not to deep discharge the batteries when they run low and I dont change then right away and a different case which can be opened without dismounting it every time...

Alex9779, 2023-09-19:
@Inrebusillis Tried to send you a mail on your homepage, no idea if that worked, contact me by mail if you want to talk, think you are in  Germany too...

Inrebusillis, 2023-09-19:
thx,
sent you a mail

Inrebusillis, 2023-09-25:
thanks,[jpmeijers](https://github.com/jpmeijers) you nailed it.
Each time the Atmega 328p wakes up (every hour), the firmware samples the ADC for 15 seconds, at a rate of 250kHz, storing the max and min values it encounters. It will therefore measure more than 15 pulses in a row, storing the maximum sample, of the maximum pulse, and report that as the voltage.

Closed 2023-09-25.

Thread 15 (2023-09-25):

DualOp Amp Use

ADebla, 2023-09-25:
Hello everyone,

I don't really think we could qualify this post as an issue but I need some more understanding about the hardware.

I have tried to simulate the circuit with the dual OP Amp as in the schematic.

I am actually wondering why it is the use of these twos ? I mean, as long the voltage divider gives the peak of the pulser trough the ADC (ofc, we need to hold the peak value to sample it).

So could maybe someone explain me a bit the use of the dual op amp please ? Because I have the impression that only the voltage divider with a cirucit that hold the value feeding the adc with his negative potential to ground will be enough.

Please do not hesitate to correct me if I am misunderstanding the concept.

Kind regards,
Antoine

jpmeijers, 2023-09-26:
"Ground" in this circuit is just some arbitrary reference that remains relatively stable over the time it takes for a single pulse to pass. Because the sensor is physically connected to the fence wires, this ground value is roughly the same as the fence idle voltage, which may or may not be the same as the actual earth voltage - due to static buildup this could be different.

If you would look at the fence pulse on an oscilloscope, you will see the pulse do not only go high above the idle voltage, but also low below the idle voltage. When I compared the readings of this sensor with another fence tester, it looks like other testers report the voltage difference between the pulse peak and trough. So in other words Vmax-Vmin.

This tester measures both the positive peak voltage as well as the negative minimum voltage. This negative voltage measurement requires the second inverting opamp cirtcuit, while the maximum voltage is measured using the normal non-inverting opamp. That's why we need both opamps.

I hope this makes sense, and I hope I did not make any mistake in my description.

ADebla, 2023-09-28:
Thank a lot for the explanation ! Indeed, it does make sense now, I did work with some fence energizer but I have to say that I did not look at the negative part after the pulse.

In addition to your explanations, I understand now with the simulation does not work. In fact, I have simulated not with a pulse but with a 3.3V DC continous voltage which refer to the 12kV maximum before the voltage divider.

As it is continous, it can output and so simulate the positive side but not the negative one. I will try to simulate again and give some results here.

As a last question and for the needs of the simulation, do you have any example of the idle voltage of the fence you worked with and where did the negative part of the pulse have been gone so far ?

Kind regards,
Antoine

ADebla, 2023-09-28:
It is indeed really relevant, thanks a lot for the help and the informations.

I think we can close the "issue" !

Closed 2023-09-28.

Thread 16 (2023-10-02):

New resistor configuration in errata.txt

djorr5, 2023-10-02:
Hi, I saw this had activity starting up not that long ago and thought I might join the party ;).

In the errata.txt. OP makes mention of changing the resistor configuration from:
 [Fence+]--[10M]--[10M]--[1M]--[Measure]--[5k8]--[Fence-/GND]

to:
 [+12kV]--[10M]--[1M]--[Measure]--[5k8]--[GND]--[10M]--[Fence-]

Assuming so that the Fence- is possible earth (as in poke in an earth spike) and GND is ground referance on the PCB. However when I put the updated resistor values into falstad.com and with a 12kV input I was reading 6.28V at the opamp input. Isn't this too high for the opamp?

Or am I completely missing something?

Sorry for making it an issue but I saw some other do it and thought this would be the best way.

Great project by the way!!

jpmeijers, 2023-10-02:
Did you remember to move the curcuit's GND connection to between the 5k8 and 10M resistor?

"GND" is just some arbitrary chosen reference. The errata changes this reference to be isolated from the fence's negative line (for two line systems). This is good, because both the "positive" and "negative" lines will shock you if you touch them, and connecting one of these lines to GND will put the circuit and antenna at that same level - ie. the antenna will shock you just like the fence.

Maybe share a screenshot of your two simulations so we can see if there isn't a mistake in there. Circuit theory says the two voltage divider circuits should result in the same voltage between GND and Measure.

djorr5, 2023-10-03:
I did move the GND connection. But what I may not have done correctly is earthed the return wire of the fence. Here (australia) majority of fences have an earth spike and run just the one hot wire. So I was just wondering if that would affect the new layout of your voltage divider. Please see screenshot of a simulation I ran. Might not have it configured correctly, but I simulated the max voltage as a DC to see the highest level. It is set at 12kV.

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

kiu, 2023-10-03:
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

djorr5, 2023-10-03:
Ah ok. Understood.

djorr5, 2023-10-03:
Ah ok. Understood.

Closed 2023-10-03.

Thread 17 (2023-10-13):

Resistors of voltage divider for battery measurement

Alex9779, 2023-10-13:
I am wondering why those resistors have the value 232R.
Does it really matter or does this have a special reason?
Or can I take also 220R or 270R?

kiu, 2023-10-13:
As long as both have the same value its fine. The lower the value the more power is wasted. Don't know why I chose those in the past and not a few kilos.

Alex9779, 2023-10-13:
Ya ok so for the time the battery is measured current flows and is basically wasted... As far as I can see about 9mA for 500ms.
So 100k like the others used on the opamp circuit would also be fine? Should then be about 21uA.

Alex9779, 2023-10-14:
Just tested with my V2 dev devices, works like a charm, measurement are equal. so I am just using 100k now...

jpmeijers, 2023-10-16:
It's a trade off.

Higher value resistors mean lower power draw, but they are more susceptible to noise, causing a fluctuating or inaccurate measurement. Also with higher value resistors one need to wait a short while for the internal ADC capacitors to charge up before doing the measurement.

With lower value voltage divider resistors, the ADC cap charges up quicker, and it's less susceptible to noise, but the power draw is higher.

What one would normally do is to connect the Bat-/GND side of the divider to a low side switch (PMOS), or just to a GPIO pin. In idle mode switch the MOSFET off, pull the GPIO high, or make the GPIO high impedance. That way there is no current flowing when you are not making a measurement. Only when a measurement is done, switch the voltage divider on, wait a millisecond or two, then do the measurement, before switching it off again. In this case one can use smaller resistors to get a more accurate reading, while not wasting power in idle mode. The trade off is a higher component count (if you use a MOSFET), or a extra GPIO used.

Some info here: https://electronics.stackexchange.com/questions/546121/placement-of-mosfets-in-switchable-voltage-divider-for-voltage-measurements

Alex9779, 2023-10-16:
Thanks for further explaining, that is how it is done on the LoFence, BAT GND is on an GPIO and switched on when measuring the battery power.
I switched to 100k on my current V2 prototypes and two are in the wild now and performing pretty well, so I think I'll stick to 100k.
The measurement time is 500ms, I did not change that from the original firmware because it seemed appropriate.
Thinking about it a bit further you mentioned charging time of the ADC caps, but the imeplemtation uses ADC in free running mode and reading the value when the ADC triggers and as far as I understood the datasheet that happens when a measurement is complete, so does this really matter? If the caps charge slower does and individual measurement of the ADC not just take a little longer and using hight resistors results in fewer triggers or the ISR method during the measurement period?
But with noise you are right but it seems to have very little influence in this case...

Alex9779, 2023-10-16:
BTW the main reason I asked was because 232R is a strange value and has a bad availability at the assembler and also costs a lot more...

Closed 2023-10-14.

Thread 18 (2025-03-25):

Power harvesting off the fence energizer?

BetterAutomations, 2025-03-25:
Since there is a resistor divider could it (theoretically) be tapped to charge a super capacitor to supply power to the circuit?

miestas-art, 2025-09-19:
I think this is an unlikely option due to how much power there is available to tap on. I.e. my 10J 14.5kV energizer **consumes** ~2W of power.

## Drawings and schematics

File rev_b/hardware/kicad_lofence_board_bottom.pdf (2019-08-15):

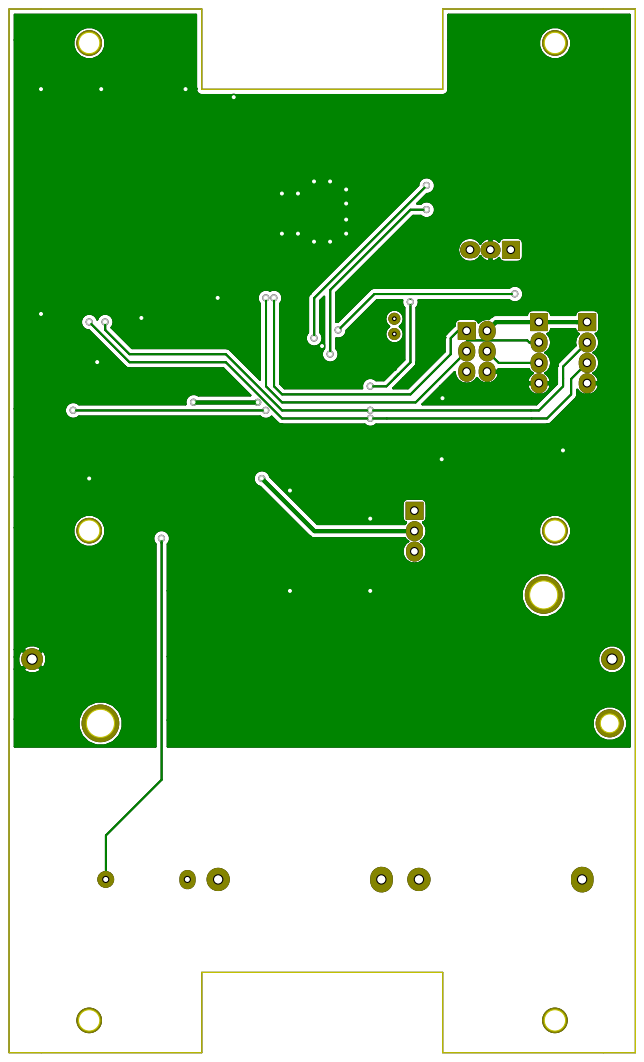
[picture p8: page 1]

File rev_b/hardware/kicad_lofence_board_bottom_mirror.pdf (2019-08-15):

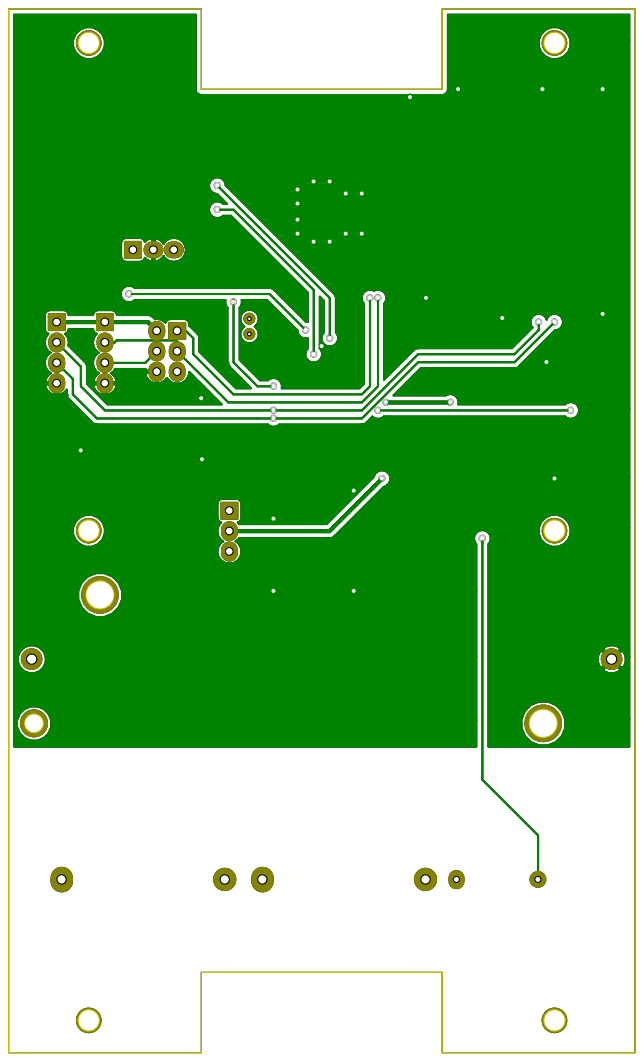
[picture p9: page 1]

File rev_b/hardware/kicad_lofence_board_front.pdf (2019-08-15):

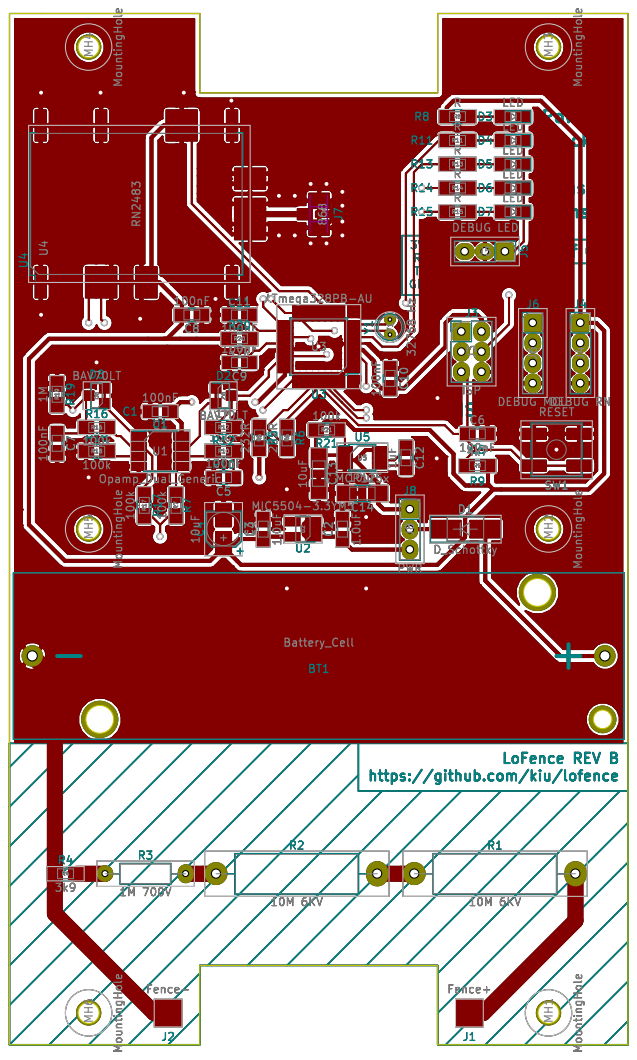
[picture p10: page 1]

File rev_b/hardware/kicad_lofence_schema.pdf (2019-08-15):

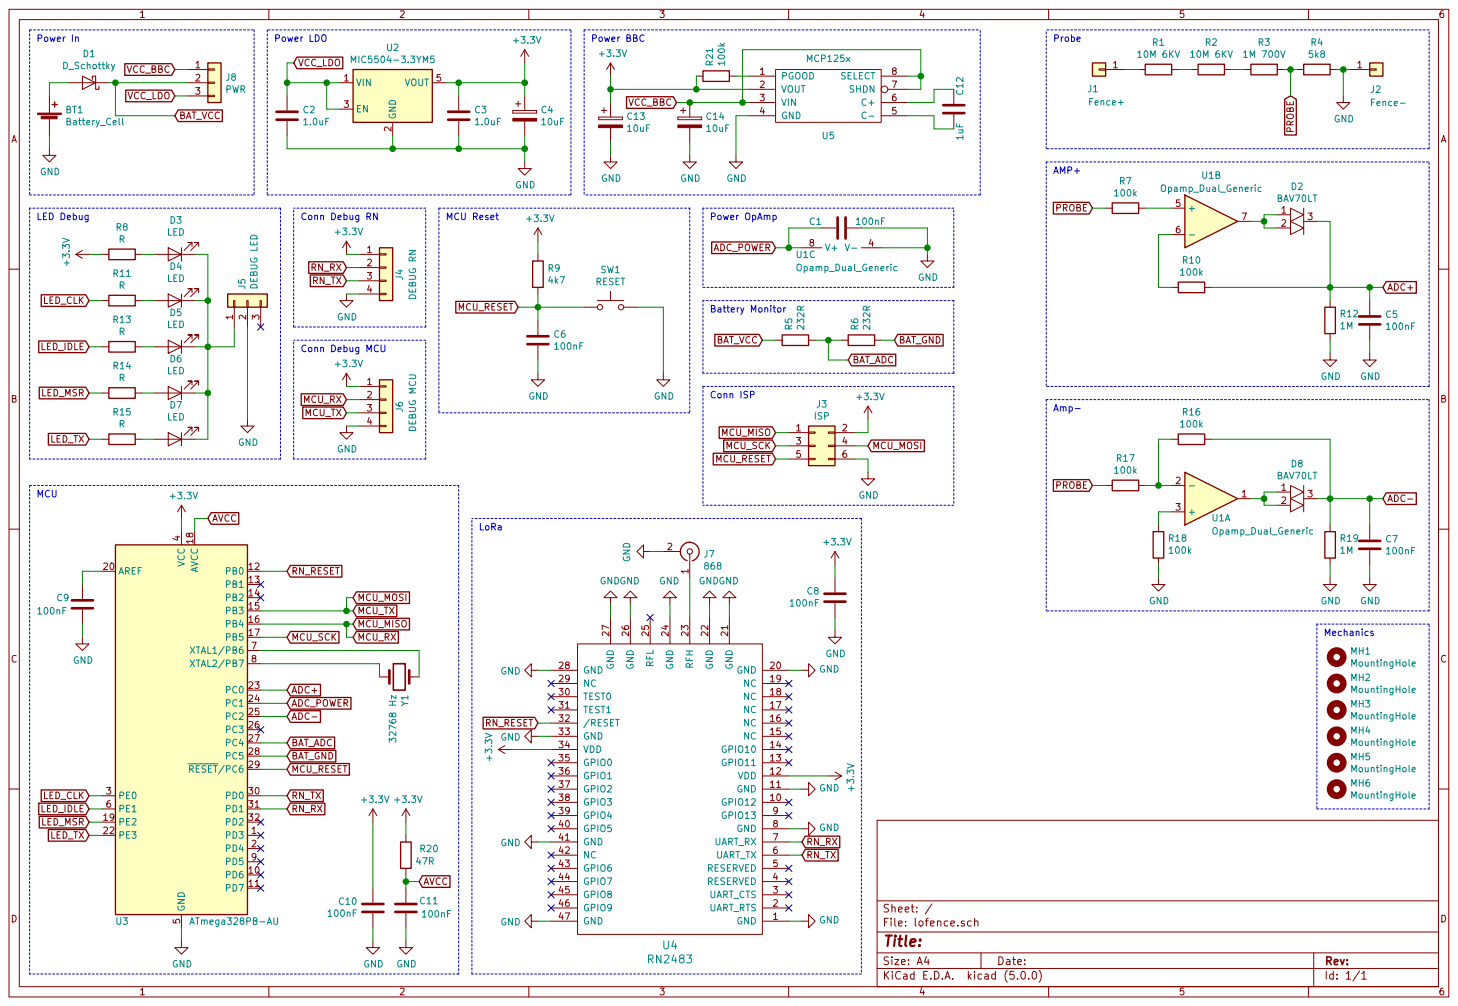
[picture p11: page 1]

Id: 1/1 Title: File: lofence.sch Sheet: /

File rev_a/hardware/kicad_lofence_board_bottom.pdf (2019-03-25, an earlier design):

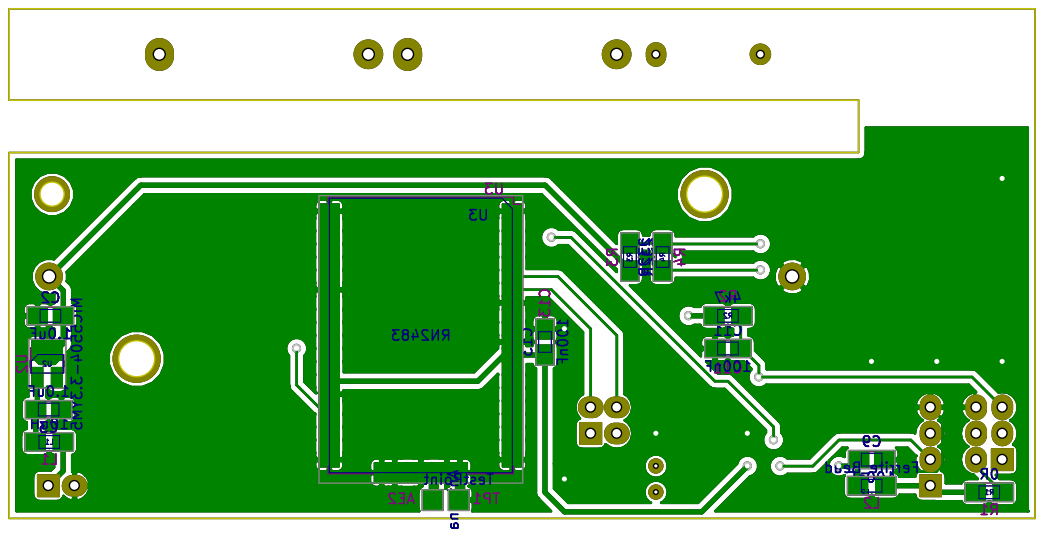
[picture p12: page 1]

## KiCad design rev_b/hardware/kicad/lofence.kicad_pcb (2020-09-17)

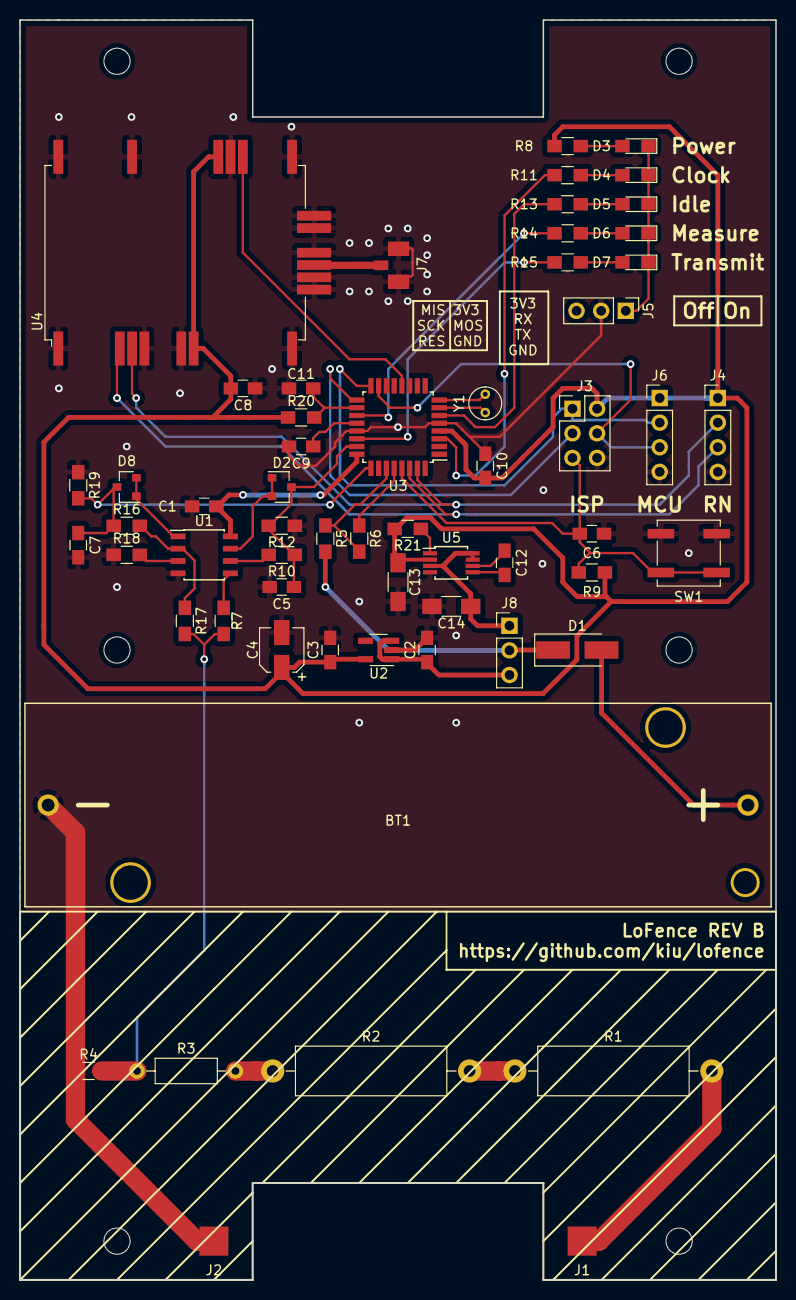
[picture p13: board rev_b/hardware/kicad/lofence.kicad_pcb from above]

Board: 2 copper layers, 78.0 x 130.0 mm, 65 parts (0 on the bottom side), 46 nets.

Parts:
BT1: Battery_Cell; 18650HolderTHT
C1, C5, C6, C7, C8, C9, C10, C11: 100nF; C_0805_HandSoldering
C2, C3: 1.0uF; C_0805_HandSoldering
C4: 10uF; CP_Elec_4x5.7
C12: 1uF; C_0805_HandSoldering
C13, C14: 10uF; C_1206_HandSoldering
D1: D_Schottky; D_SMA_Handsoldering
D2, D8: BAV70LT; SOT-23
D3, D4, D5, D6, D7: LED; LED_0805_HandSoldering
J1: Fence+; Measurement_Point_Square-SMD-Pad_Big
J2: Fence-; Measurement_Point_Square-SMD-Pad_Big
J3: ISP; Pin_Header_Straight_2x03_Pitch2.54mm
J4: DEBUG RN; Pin_Header_Straight_1x04_Pitch2.54mm
J5: DEBUG LED; Pin_Header_Straight_1x03_Pitch2.54mm
J6: DEBUG MCU; Pin_Header_Straight_1x04_Pitch2.54mm
J7: 868; U.FL
J8: PWR; Pin_Header_Straight_1x03_Pitch2.54mm
MH1, MH2, MH3, MH4, MH5, MH6: MountingHole; MountingHole_2.7mm_M2.5
R1, R2: 10M 6KV; R_Axial_DIN0516_L15.5mm_D5.0mm_P20.32mm_Horizontal
R3: 1M 700V; R_Axial_DIN0207_L6.3mm_D2.5mm_P10.16mm_Horizontal
R4: 3k9; R_0805_HandSoldering
R5, R6: 232R; R_0805_HandSoldering
R7, R10, R16, R17, R18, R21: 100k; R_0805_HandSoldering
R8, R11, R13, R14, R15: R; R_0805_HandSoldering
R9: 4k7; R_0805_HandSoldering
R12, R19: 1M; R_0805_HandSoldering
R20: 47R; R_0805_HandSoldering
SW1: RESET; SW_SPST_B3SL-1002P
U1: Opamp_Dual_Generic; SOIC-8_3.9x4.9mm_Pitch1.27mm
U2: MIC5504-3.3YM5; SOT-23-5_HandSoldering
U3: ATmega328PB-AU; TQFP-32_7x7mm_Pitch0.8mm
U4: RN2483; RN2483_serial
U5: MCP125x; MSOP-8_3x3mm_Pitch0.65mm
Y1: 32768 Hz; Crystal_Round_d3.0mm_Vertical

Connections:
+3V3: C3.1, C4.1, C8.2, C10.2, C13.1, J3.2, J4.1, J6.1, R8.2, R9.1, R20.1, R21.2, U2.5, U3.4, U4.12, U4.34, U5.2
ADC+: C5.1, D2.3, R10.1, R12.2, U3.23
ADC-: C7.1, D8.3, R16.1, R19.2, U3.25
ADC_POWER: C1.1, U1.8, U3.24
AVCC: C11.2, R20.2, U3.18
BAT_ADC: R5.1, R6.2, U3.27
BAT_GND: R6.1, U3.28
BAT_VCC: D1.1, J8.2, R5.2
GND: BT1.2, C1.2, C2.2, C3.2, C4.2, C5.2, C6.2, C7.2, C8.1, C9.2, C10.1, C11.1, C13.2, C14.2, J2.1, J3.6, J4.4, J5.2, J6.4, J7.2, R4.1, R12.1, R18.1, R19.1, SW1.2, U1.4, U2.2, U3.5, U3.21, U4.1, U4.8, U4.11, U4.20, U4.21, U4.22, U4.24, U4.26, U4.27, U4.28, U4.33, U4.41, U4.47, U5.4
LED_CLK: R11.2, U3.3
LED_IDLE: R13.2, U3.6
LED_MSR: R14.2, U3.19
LED_TX: R15.2, U3.22
MCU_MISO: J3.1, J6.2, U3.16
MCU_MOSI: J3.4, J6.3, U3.15
MCU_RESET: C6.1, J3.5, R9.2, SW1.1, U3.29
MCU_SCK: J3.3, U3.17
unnamed: BT1.1, D1.2
unnamed: C9.1, U3.20
unnamed: C12.1, U5.6
unnamed: C12.2, U5.5
unnamed: D2.1, D2.2, U1.7
unnamed: D3.1, D4.1, D5.1, D6.1, D7.1, J5.1
unnamed: D3.2, R8.1
unnamed: D4.2, R11.1
unnamed: D5.2, R13.1
unnamed: D6.2, R14.1
unnamed: D7.2, R15.1
unnamed: D8.1, D8.2, U1.1
unnamed: J1.1, R1.2
unnamed: J7.1, U4.23
unnamed: R1.1, R2.2
unnamed: R2.1, R3.2
unnamed: R7.1, U1.5
unnamed: R10.2, U1.6
unnamed: R16.2, R17.1, U1.2
unnamed: R18.2, U1.3
unnamed: R21.1, U5.1
unnamed: U3.7, Y1.1
unnamed: U3.8, Y1.2
PROBE: R3.1, R4.2, R7.2, R17.2
RN_RESET: U3.12, U4.32
RN_RX: J4.2, U3.31, U4.7
RN_TX: J4.3, U3.30, U4.6
VCC_BBC: C14.1, J8.1, U5.3, U5.7, U5.8
VCC_LDO: C2.1, J8.3, U2.1, U2.3

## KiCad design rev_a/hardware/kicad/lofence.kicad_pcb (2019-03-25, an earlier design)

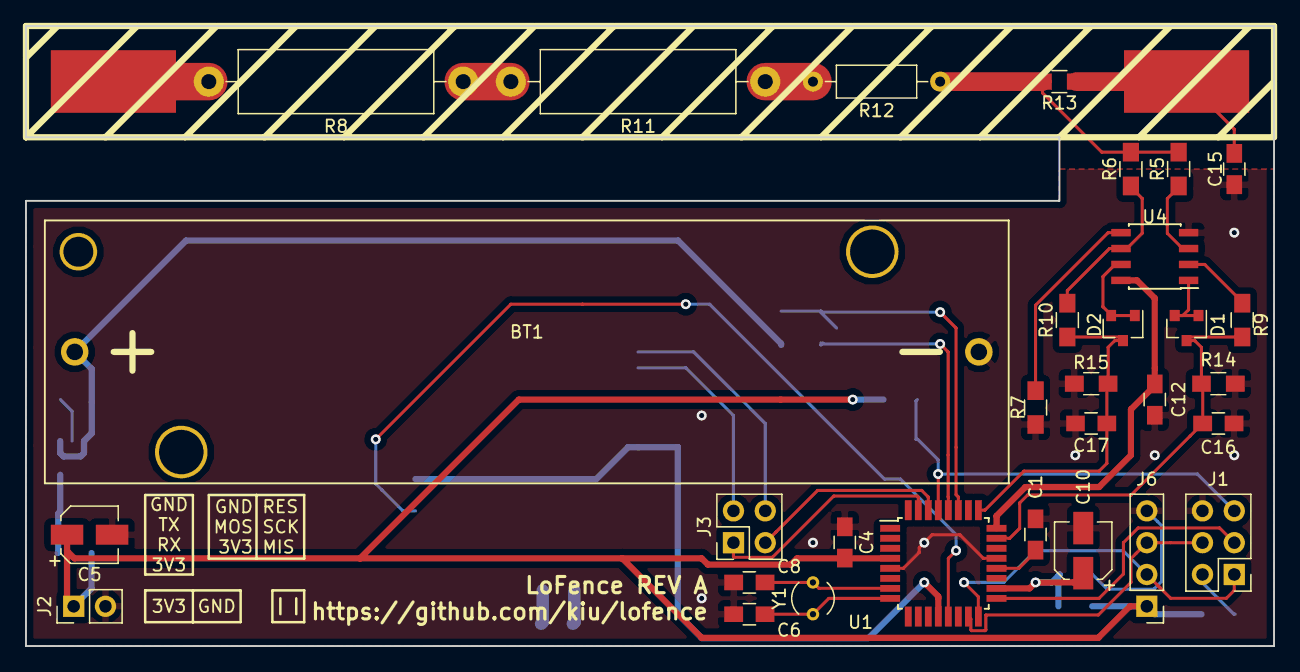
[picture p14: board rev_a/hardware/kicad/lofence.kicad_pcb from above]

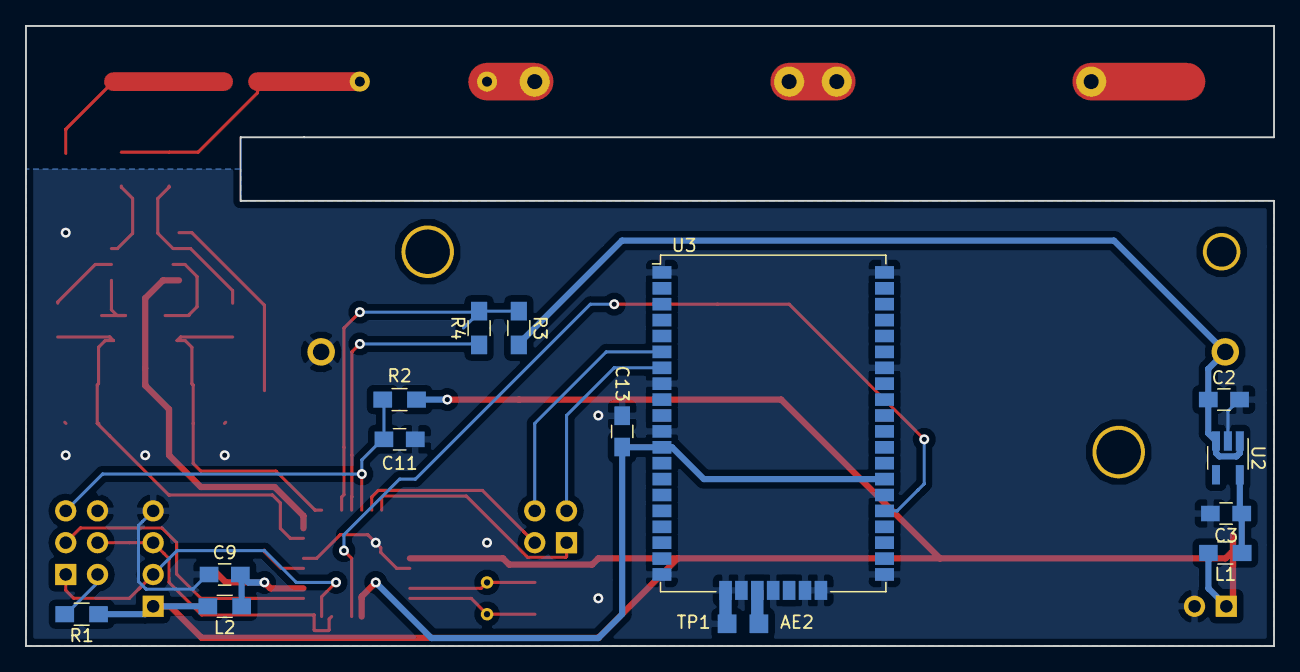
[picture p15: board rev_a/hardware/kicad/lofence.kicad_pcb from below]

Board: 2 copper layers, 99.7 x 49.5 mm, 48 parts (15 on the bottom side), 36 nets.

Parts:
AE2: Antenna; Measurement_Point_Square-SMD-Pad_Small
BT1: Battery_Cell; 18650HolderTHT
C1, C4, C9, C11, C12, C13, C16, C17: 100nF; C_0805_HandSoldering
C2, C3: 1.0uF; C_0805_HandSoldering
C5, C10: 10uF; CP_Elec_4x5.7
C6, C8: 0pF; C_0805_HandSoldering
C15: 0nF; C_0805_HandSoldering
D1, D2: BAV70LT; SOT-23
J1: ISP; Pin_Header_Straight_2x03_Pitch2.54mm
J2: POWER; Pin_Header_Straight_1x02_Pitch2.54mm
J3: DEBUG RN2483; Pin_Header_Straight_2x02_Pitch2.54mm
J5: Fence+; SolderWirePad_single_SMD_5x10mm
J6: DEBUG RXTX; Pin_Header_Straight_1x04_Pitch2.54mm
J7: Fence-; SolderWirePad_single_SMD_5x10mm
L1: 10uH; R_0805_HandSoldering
L2: Ferrite_Bead; R_0805_HandSoldering
R1: 0R; R_0805_HandSoldering
R2: 4k7; R_0805_HandSoldering
R3, R4: 232R; R_0805_HandSoldering
R5, R6, R7, R9, R10: 100k; R_0805_HandSoldering
R8, R11: 10M 6KV; R_Axial_DIN0516_L15.5mm_D5.0mm_P20.32mm_Horizontal
R12: 1M 700V; R_Axial_DIN0207_L6.3mm_D2.5mm_P10.16mm_Horizontal
R13: 3k9; R_0805_HandSoldering
R14, R15: 1M; R_0805_HandSoldering
TP1: TestPoint; Measurement_Point_Square-SMD-Pad_Small
U1: ATmega328PB-AU; TQFP-32_7x7mm_Pitch0.8mm
U2: MIC5504-3.3YM5; SOT-23-5_HandSoldering
U3: RN2483
U4: Opamp_Dual_Generic; SOIC-8_3.9x4.9mm_Pitch1.27mm
Y1: 32768 Hz; Crystal_AT310_d3.0mm_l10.0mm_Vertical

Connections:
+3.3VADC: C9.2, C10.1, L2.1, U1.18
+3V3: C4.2, C5.1, J2.1, J6.1, L1.2, L2.2, R1.1, R2.1, U1.4
ADC+: C16.1, D1.3, R9.1, R14.2, U1.23
ADC-: C17.1, D2.3, R10.1, R15.2, U1.25
ADC_POWER: C12.2, U1.24, U4.8
BAT_ADC: R3.1, R4.2, U1.27
BAT_GND: R4.1, U1.28
BAT_VCC: BT1.1, C2.1, R3.2, U2.1, U2.3
GND: BT1.2, C1.2, C2.2, C3.2, C4.1, C5.2, C6.1, C8.1, C9.1, C10.2, C11.2, C12.1, C13.1, C15.2, C16.2, C17.2, J1.6, J2.2, J6.4, R7.1, R14.1, R15.1, TP1.1, U1.5, U1.21, U2.2, U3.1, U3.8, U3.11, U3.20, U3.21, U3.22, U3.24, U3.26, U3.27, U3.28, U3.33, U3.41, U3.47, U4.4
MCU_DBG_RX: J1.1, J6.2, U1.16
MCU_DBG_TX: J1.4, J6.3, U1.15
MCU_RESET: C11.1, J1.5, R2.2, U1.29
MCU_RX: J3.3, U1.30
MCU_SCK: J1.3, U1.17
MCU_TX: J3.1, U1.31
unnamed: AE2.1, U3.23
unnamed: C1.1, U1.20
unnamed: C3.1, L1.1, U2.5
unnamed: C6.2, U1.8, Y1.1
unnamed: C8.2, U1.7, Y1.2
unnamed: C15.1, J7.1, R13.1
unnamed: D1.1, D1.2, U4.1
unnamed: D2.1, D2.2, U4.7
unnamed: J1.2, R1.2
unnamed: J5.1, R8.2
unnamed: R5.1, U4.3
unnamed: R7.2, U4.5
unnamed: R9.2, U4.2
unnamed: R6.1, R10.2, U4.6
unnamed: R11.1, R12.2
unnamed: R8.1, R11.2
PROBE: R5.2, R6.2, R12.1, R13.2
RN_POWER: C13.2, U1.12, U3.12, U3.34
RN_RESET: U1.13, U3.32
RN_RX: J3.2, U3.7
RN_TX: J3.4, U3.6

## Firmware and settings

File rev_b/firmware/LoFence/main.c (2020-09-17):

#include <atmel_start.h>
#include <util/delay.h>
#include <string.h>
#include <stdio.h>
#include "main.h"

#define MAX(x, y) (((x) > (y)) ? (x) : (y))
#define MIN(x, y) (((x) < (y)) ? (x) : (y))

volatile uint32_t seconds = 0;

volatile uint8_t adc_clear = 0;
volatile uint8_t adc_max = 0;
volatile uint8_t adc_min = 0;
//volatile uint32_t adc_samples = 0;
uint8_t adc_val = 0;

char buffer_dbg [256];
char buffer_rn [256];
	
uint16_t volt_bat = 0;
uint16_t volt_fence_plus = 0;
uint16_t volt_fence_minus = 0;

uint16_t rounds = 0;

// ----------------------------------------------------------------------------------------------

ISR(TIMER2_OVF_vect) {
	// see https://www.mikrocontroller.net/articles/AVR-GCC-Tutorial/Die_Timer_und_Z%C3%A4hler_des_AVR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
	TCCR2B = TCCR2B;
	seconds++;	
	LED_CLK_toggle_level();
	while(ASSR & ((1<<TCN2UB) | (1<<OCR2AUB) | (1<<OCR2BUB) | (1<<TCR2AUB) | (1<<TCR2BUB)));
}

ISR(ADC_vect) {
	adc_val = ADCH;
	if (adc_clear == 1) {
		adc_clear = 0;
		adc_max = 0x00;
		adc_min = 0xFF;
//		adc_samples = 0;
	}
	adc_max = MAX(adc_max, adc_val);
	adc_min = MIN(adc_min, adc_val);
//	adc_samples++;
}

// ----------------------------------------------------------------------------------------------

void adc_init() {
	#ifdef DEBUG
	debug("ADC initialization\r\n");
	#endif

	PRR0 &= ~(1 << PRADC); // Enable
	
	DIDR0 = (1 << ADC0D) | (1 << ADC2D) | (1 << ADC4D); // Disable input buffer
	
	ADMUX = 0x00;
	ADMUX |= (0 << REFS1) | (1 << REFS0); // AVCC with external capacitor at AREF pin
	ADMUX |= (1 << ADLAR); // Left Adjust Result: enabled
	
	ADCSRA = 0x00;
	ADCSRA |= (1 << ADATE); // Auto Trigger: enabled
	ADCSRA |= (1 << ADIE); // ADC Interrupt: enabled
	
	// Safe range: 50khz - 200khz
	//ADCSRA |= (1 << ADPS2) | (0 << ADPS1) | (0 << ADPS0); // 100  16 500khz
	ADCSRA |= (1 << ADPS2) | (0 << ADPS1) | (1 << ADPS0); // 101  32 250khz
	//ADCSRA |= (1 << ADPS2) | (1 << ADPS1) | (0 << ADPS0); // 110  64 125khz
	//ADCSRA |= (1 << ADPS2) | (1 << ADPS1) | (1 << ADPS0); // 111 128  62khz
	
	ADCSRB = 0x00;
	ADCSRB |= (0 << ADTS2) | (0 << ADTS1) | (0 << ADTS0); // Free Running mode
	ADCSRB |= (0 << ACME); // Analog Comparator Multiplexer: disabled

	ACSR |= (1 << ACD); // Disable Comparator

	ADCSRA &= ~(1 << ADEN); // Disable ADC
	PRR0 |= (1 << PRADC); // Disable ADC
	
	#ifdef DEBUG
	debug("\r\n");
	#endif
}

void rn2483_init_error() {
	#ifdef DEBUG
	debug("Aborting initialization due to unexpected response\r\n");
	#endif

	rn2483_tx("sys sleep 86400000\r\n");
	
	while(1) {
		LED_TX_set_level(true);
		_delay_ms(200);
		LED_TX_set_level(false);
		_delay_ms(200);
	}
}

void rn2483_init() {
	#ifdef DEBUG
	debug("RN2483 initialization\r\n");
	#endif

	// Reset RN2483
	RN_RESET_set_level(false);
	_delay_ms(1);
	RN_RESET_set_level(true);
	_delay_ms(1000);

	rn2483_break_and_baud();
	
	rn2483_tx("sys get ver\r\n");
	rn2483_rx();

	rn2483_tx("sys get hweui\r\n");
	rn2483_rx();

	#ifdef FACTORY_RESET
	rn2483_tx("sys factoryRESET\r\n");
	_delay_ms(5000);
	rn2483_break_and_baud();
	while(1) {
		rn2483_rx();
	}
	#endif
	
	rn2483_tx("mac set adr on\r\n");
	rn2483_rx();

	sprintf (buffer_rn, "mac set devaddr %s\r\n", devAddr);
	rn2483_tx(buffer_rn);
	rn2483_rx();
	if (strcmp(buffer_rn, "ok\r\n") != 0) {
		rn2483_init_error();
		return;
	}

	sprintf (buffer_rn, "mac set nwkskey %s\r\n", nwkSKey);
	rn2483_tx(buffer_rn);
	rn2483_rx();
	if (strcmp(buffer_rn, "ok\r\n") != 0) {
		rn2483_init_error();
		return;
	}

	sprintf (buffer_rn, "mac set appskey %s\r\n", appSKey);
	rn2483_tx(buffer_rn);
	rn2483_rx();
	if (strcmp(buffer_rn, "ok\r\n") != 0) {
		rn2483_init_error();
		return;
	}
	
	rn2483_tx("sys sleep 86400000\r\n");

	#ifdef DEBUG
	debug("\r\n");
	#endif

}

// ----------------------------------------------------------------------------------------------

void power_save(uint32_t sec) {
	seconds = 0;
	sleep_enable();
	while (seconds <= sec) {
		sleep_mode();
	}
	sleep_disable();
}

void debug(char buf[]) {
	#ifdef DEBUG
	for (uint8_t i = 0; i < strlen(buf); i++) {
		while (!USART_1_is_tx_ready()) {}
		USART_1_write(buf[i]);
	}	
	while (USART_1_is_tx_busy()) {}
	#endif
}

void rn2483_break_and_baud() {
	#ifdef DEBUG
	debug ("RN2483 wakeup and baud change\r\n");
	#endif
	
	USART_0_disable();

	RN_TX_set_level(false);
	_delay_ms(5);
	RN_TX_set_level(true);

	USART_0_enable();
	
	while (!USART_0_is_tx_ready()) {}
	USART_0_write(0x55);
	
	rn2483_rx_clear();
}

void rn2483_tx(char buf[]) {
	#ifdef DEBUG
	debug("RN2483 TX: ");
	debug(buf);
	#endif
	
	for (uint8_t i = 0; i < strlen(buf); i++) {
		while (!USART_0_is_tx_ready()) {}
		USART_0_write(buf[i]);
	}
	while (USART_0_is_tx_busy()) {}
}

void rn2483_rx_clear() {
	#ifdef DEBUG
	debug("RN2483 RX clearing\r\n");
	#endif
		
	while(USART_0_is_rx_ready()) {
		while(USART_0_is_rx_ready()) {
			USART_0_read();
		}
		_delay_ms(100);
	}

}

void rn2483_rx() {
	char nc = 0x00;
	uint8_t len = 0;

	for (; len < 255; len++) {
		nc = USART_0_read();		
		buffer_rn[len] = nc;
		if (nc == '\n') {
			break;
		}
	}
	buffer_rn[len+1] = '\0';
	
	#ifdef DEBUG
	debug("RN2483 RX: ");
	debug(buffer_rn);
	#endif
}

// ----------------------------------------------------------------------------------------------

void measure() {
	LED_MSR_set_level(true);
	#ifdef DEBUG
	debug("Measuring\r\n");
	#endif
		
	// ----------------------------------------------------------------------------------------------

	PRR0 &= ~(1 << PRADC); // Enable ADC
	ADC_POWER_set_level(true);
	_delay_ms(1000);
		
	// ----------------------------------------------------------------------------------------------
		
	#ifdef DEBUG
	debug("Measuring battery: ");
	#endif

	BAT_GND_set_level(false);
	_delay_ms(1000);

	ADMUX = (ADMUX & 0xE0) | (1 << MUX2); // Pin 4
	ADCSRA |= (1 << ADEN);
	ADCSRA |= (1 << ADSC);
	adc_clear = 1;
	_delay_ms(500);
	ADCSRA &= ~(1 << ADEN);
	BAT_GND_set_level(true);

	volt_bat = (((330000/255*adc_min*2) - 0))/100;

	#ifdef DEBUG
	sprintf (buffer_dbg, "%d mV\r\n", volt_bat);
	debug(buffer_dbg);
	#endif

	// ----------------------------------------------------------------------------------------------

	#ifdef DEBUG
	debug("Measuring fence positive: ");
	#endif
				
	ADMUX = (ADMUX & 0xE0); // Pin 0
	ADCSRA |= (1 << ADEN);
	ADCSRA |= (1 << ADSC);
	adc_clear = 1;
	_delay_ms(MEASURE_MS);
	ADCSRA &= ~(1 << ADEN);

	volt_fence_plus = (12000/255*adc_max);

	#ifdef DEBUG
	sprintf (buffer_dbg, "%d V\r\n", volt_fence_plus);
	debug(buffer_dbg);
	#endif

	// ----------------------------------------------------------------------------------------------

	#ifdef DEBUG
	debug("Measuring fence negative: ");
	#endif

	ADMUX = (ADMUX & 0xE0) | (1 << MUX1); // Pin 2
	ADCSRA |= (1 << ADEN);
	ADCSRA |= (1 << ADSC);
	adc_clear = 1;
	_delay_ms(MEASURE_MS);
	ADCSRA &= ~(1 << ADEN);

	volt_fence_minus = (12000/255*adc_max);

	#ifdef DEBUG
	sprintf (buffer_dbg, "%d V\r\n", volt_fence_minus);
	debug(buffer_dbg);
	#endif

	// ----------------------------------------------------------------------------------------------

	ADC_POWER_set_level(false);
	PRR0 |= (1 << PRADC); // Disable ADC

	LED_MSR_set_level(false);
	#ifdef DEBUG
	debug("\r\n");
	#endif
}

void transmit_error() {
	#ifdef DEBUG
	debug("Aborting transmission due to unexpected response\r\n");
	#endif

	rn2483_tx("sys sleep 86400000\r\n");
	
	#ifdef DEBUG
	debug("\r\n");
	#endif
	
	for (uint8_t i = 0; i < 20; i++) {
		LED_TX_set_level(true);
		_delay_ms(200);
		LED_TX_set_level(false);
		_delay_ms(200);		
	}
}

void transmit() {
	LED_TX_set_level(true);
	#ifdef DEBUG
	debug("Transmitting\r\n");
	#endif

	rn2483_break_and_baud();

	rn2483_tx("mac join abp\r\n");
	rn2483_rx();
	if (strcmp(buffer_rn, "ok\r\n") != 0) {
		transmit_error();
		return;
	}
	rn2483_rx();
	if (strcmp(buffer_rn, "accepted\r\n") != 0) {
		transmit_error();
		return;
	}

	rn2483_tx("mac get upctr\r\n");
	rn2483_rx();

	rn2483_tx("mac set pwridx 1\r\n"); // 5 = low power, 1 = high power
	rn2483_rx();
	if (strcmp(buffer_rn, "ok\r\n") != 0) {
		transmit_error();
		return;
	}

	sprintf (buffer_rn, "mac tx uncnf 1 %04X%04X%04X%04X\r\n", rounds, volt_bat, volt_fence_plus, volt_fence_minus);
	rn2483_tx(buffer_rn);
	rn2483_rx();
	if (strcmp(buffer_rn, "ok\r\n") != 0) {
		transmit_error();
		return;	
	}
	rn2483_rx();
	if (strcmp(buffer_rn, "mac_tx_ok\r\n") != 0) {
		transmit_error();
		return;
	}

	rn2483_tx("mac save\r\n");
	rn2483_rx();		
	if (strcmp(buffer_rn, "ok\r\n") != 0) {
		transmit_error();
		return;
	}
	
	rn2483_tx("sys sleep 86400000\r\n");
	
	LED_TX_set_level(false);
	#ifdef DEBUG
	debug("\r\n");
	#endif
}

void pause() {
	LED_IDLE_set_level(true);
	#ifdef DEBUG
	sprintf (buffer_dbg, "Sleeping for %d seconds\r\n", INTERVAL_SECONDS);
	debug(buffer_dbg);
	_delay_ms(500);
	#endif
	
	power_save(INTERVAL_SECONDS);
	
	LED_IDLE_set_level(false);
	#ifdef DEBUG
	debug("\r\n");
	#endif
}

// ----------------------------------------------------------------------------------------------

int main(void) {

	atmel_start_init();

	LED_IDLE_set_level(true);
	LED_MSR_set_level(true);
	LED_TX_set_level(true);

	#ifdef DEBUG
	debug("\r\n");
	debug("\r\n");
	debug("LoFence REV B v0.4 by kiu\r\n");
	debug("https://github.com/kiu/lofence\r\n");
	debug("Lets get started!\r\n");
	debug("\r\n");
	#endif
	LED_IDLE_set_level(false);

	adc_init();
	LED_MSR_set_level(false);

	rn2483_init();			
	LED_TX_set_level(false);
		
	while (1) {
		
		#ifdef DEBUG
		sprintf(buffer_dbg, "Round: %u\r\n", rounds);
		debug(buffer_dbg);
		#endif
		
		measure();
		
		transmit();		
		
		pause();		

		rounds++;
	}
	
}

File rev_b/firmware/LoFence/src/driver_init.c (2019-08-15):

/**
 * \file
 *
 * \brief Driver initialization.
 *
 (c) 2018 Microchip Technology Inc. and its subsidiaries.

    Subject to your compliance with these terms,you may use this software and
    any derivatives exclusively with Microchip products.It is your responsibility
    to comply with third party license terms applicable to your use of third party
    software (including open source software) that may accompany Microchip software.

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
    IN NO EVENT WILL MICROCHIP BE LIABLE FOR ANY INDIRECT, SPECIAL, PUNITIVE,
    INCIDENTAL OR CONSEQUENTIAL LOSS, DAMAGE, COST OR EXPENSE OF ANY KIND
    WHATSOEVER RELATED TO THE SOFTWARE, HOWEVER CAUSED, EVEN IF MICROCHIP HAS
    BEEN ADVISED OF THE POSSIBILITY OR THE DAMAGES ARE FORESEEABLE. TO THE
    FULLEST EXTENT ALLOWED BY LAW, MICROCHIP'S TOTAL LIABILITY ON ALL CLAIMS IN
    ANY WAY RELATED TO THIS SOFTWARE WILL NOT EXCEED THE AMOUNT OF FEES, IF ANY,
    THAT YOU HAVE PAID DIRECTLY TO MICROCHIP FOR THIS SOFTWARE.
 *
 */

/*
 * Code generated by START.
 *
 * This file will be overwritten when reconfiguring your START project.
 * Please copy examples or other code you want to keep to a separate file
 * to avoid losing it when reconfiguring.
 */

#include "driver_init.h"
#include <system.h>

void TIMER_RTC_initialization(void)
{

	TIMER_RTC_init();
}

/* configure pins and initialize registers */
void USART_0_initialization(void)
{

	// Set pin direction to input
	RN_RX_set_dir(PORT_DIR_IN);

	RN_RX_set_pull_mode(
	    // <y> Pull configuration
	    // <id> pad_pull_config
	    // <PORT_PULL_OFF"> Off
	    // <PORT_PULL_UP"> Pull-up
	    PORT_PULL_OFF);

	// Set pin direction to output
	RN_TX_set_dir(PORT_DIR_OUT);

	RN_TX_set_level(
	    // <y> Initial level
	    // <id> pad_initial_level
	    // <false"> Low
	    // <true"> High
	    false);

	USART_0_init();
}

/* configure pins and initialize registers */
void USART_1_initialization(void)
{

	// Set pin direction to input
	MCU_RX_set_dir(PORT_DIR_IN);

	MCU_RX_set_pull_mode(
	    // <y> Pull configuration
	    // <id> pad_pull_config
	    // <PORT_PULL_OFF"> Off
	    // <PORT_PULL_UP"> Pull-up
	    PORT_PULL_UP);

	// Set pin direction to output
	MCU_TX_set_dir(PORT_DIR_OUT);

	MCU_TX_set_level(
	    // <y> Initial level
	    // <id> pad_initial_level
	    // <false"> Low
	    // <true"> High
	    false);

	USART_1_init();
}

/**
 * \brief System initialization
 */
void system_init()
{
	mcu_init();

	/* PORT setting on PB0 */

	// Set pin direction to output
	RN_RESET_set_dir(PORT_DIR_OUT);

	RN_RESET_set_level(
	    // <y> Initial level
	    // <id> pad_initial_level
	    // <false"> Low
	    // <true"> High
	    true);

	/* PORT setting on PC0 */

	// Disable pull-up.
	ADC_PLUS_set_pull_mode(PORT_PULL_OFF);

	/* PORT setting on PC1 */

	// Set pin direction to output
	ADC_POWER_set_dir(PORT_DIR_OUT);

	ADC_POWER_set_level(
	    // <y> Initial level
	    // <id> pad_initial_level
	    // <false"> Low
	    // <true"> High
	    false);

	/* PORT setting on PC2 */

	// Disable pull-up.
	ADC_MINUS_set_pull_mode(PORT_PULL_OFF);

	/* PORT setting on PC4 */

	// Disable pull-up.
	BAT_ADC_set_pull_mode(PORT_PULL_OFF);

	/* PORT setting on PC5 */

	// Set pin direction to output
	BAT_GND_set_dir(PORT_DIR_OUT);

	BAT_GND_set_level(
	    // <y> Initial level
	    // <id> pad_initial_level
	    // <false"> Low
	    // <true"> High
	    true);

	/* PORT setting on PE0 */

	// Set pin direction to output
	LED_CLK_set_dir(PORT_DIR_OUT);

	LED_CLK_set_level(
	    // <y> Initial level
	    // <id> pad_initial_level
	    // <false"> Low
	    // <true"> High
	    false);

	/* PORT setting on PE1 */

	// Set pin direction to output
	LED_IDLE_set_dir(PORT_DIR_OUT);

	LED_IDLE_set_level(
	    // <y> Initial level
	    // <id> pad_initial_level
	    // <false"> Low
	    // <true"> High
	    false);

	/* PORT setting on PE2 */

	// Set pin direction to output
	LED_MSR_set_dir(PORT_DIR_OUT);

	LED_MSR_set_level(
	    // <y> Initial level
	    // <id> pad_initial_level
	    // <false"> Low
	    // <true"> High
	    false);

	/* PORT setting on PE3 */

	// Set pin direction to output
	LED_TX_set_dir(PORT_DIR_OUT);

	LED_TX_set_level(
	    // <y> Initial level
	    // <id> pad_initial_level
	    // <false"> Low
	    // <true"> High
	    false);

	sysctrl_init();

	FLASH_0_init();

	TIMER_RTC_initialization();

	USART_0_initialization();

	USART_1_initialization();
}

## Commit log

2019-03-25 init REV A
    [lofence-B.Cu.gbl, lofence-B.Mask.gbs, lofence-B.SilkS.gbo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]
2019-08-15 REV B is ready for real world usage
    [bom.ods, calculations.ods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]
2020-02-09 Corrected value of R4 in BOM
    [bom.ods]
2020-09-17 Fixed BOM for R5 + R6 (0805 instead of 1206)
    [bom.ods]
2020-09-17 Fixed silkscreen for ISP connector
    [lofence.kicad_pcb]
